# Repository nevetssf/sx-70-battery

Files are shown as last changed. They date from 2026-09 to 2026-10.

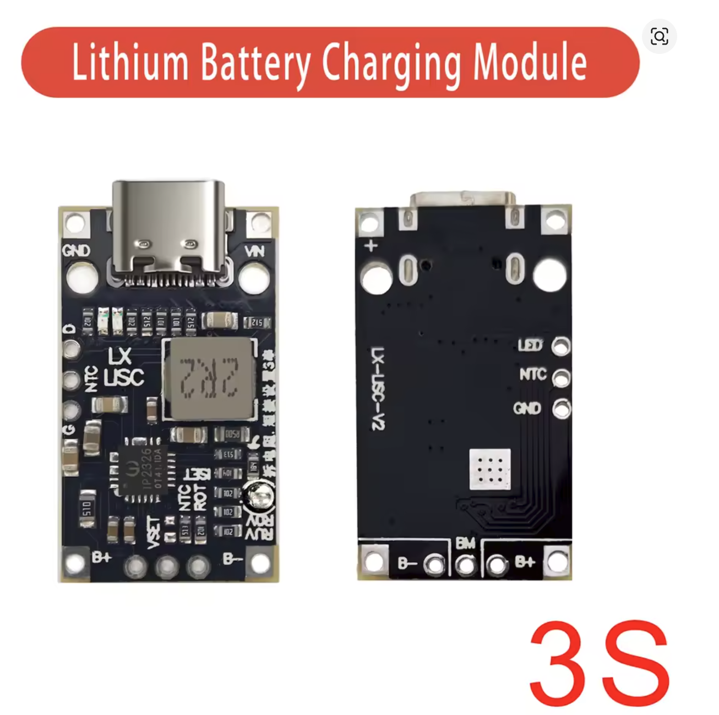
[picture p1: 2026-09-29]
hardware/bom/U2-ip2326-charger/ip2326-black-3s-lx-lsc-v2-front-back.png

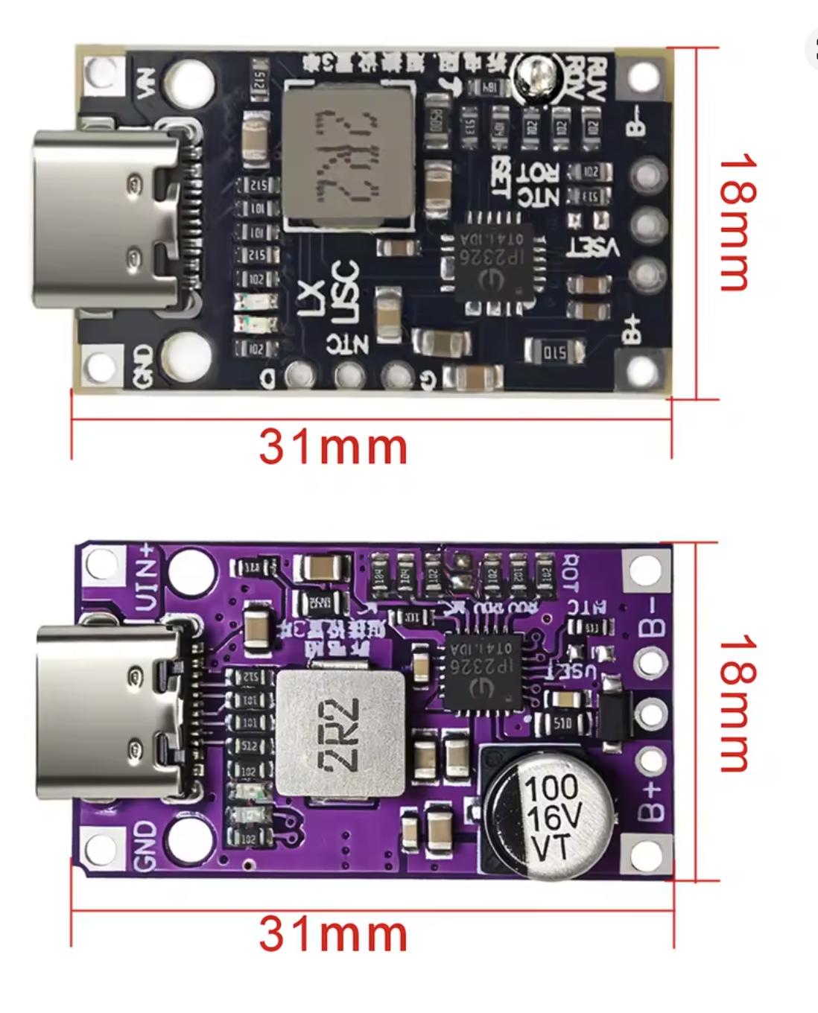
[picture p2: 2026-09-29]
hardware/bom/U2-ip2326-charger/ip2326-dimensions-31x18mm.png

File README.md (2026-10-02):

# SX-70 External Power Pack

A rechargeable, camera-mounted power supply for the folding Polaroid SX-70, replacing the PolaPulse cell in the film pack. Aimed at battery-less film (i-Type), dead packs, and bench work.

**Status: design v0.4, not yet built.** Nothing has been measured on a camera yet. See [Where things stand](#where-things-stand).

## Where things stand

**Settled**

| | |
|---|---|
| Camera interface | Two **pogo pins** onto the base-plate contacts, through 3 mm holes in the skin. **No soldering to the camera** |
| Mounting | Magnets bonded into the pack base, against a VHB-bonded steel shim on the camera |
| Enclosure | 3D printed PETG, M2.5 brass heat-set inserts, magnet pockets and pogo bosses in the base |
| Architecture | Still two options. The measured motor peak current decides between them |
| Envelope (Option B) | **86 × 50 × 17.7 mm** |

**Ordered** — replacement flex parts, in case a flex fails (see [flex-order.md](docs/flex-order.md))

- **Body flex** — Cundari's replacement, ordered from PCBWay, shipped Sept 2026
- **Motor control chips** — 10 assembled boards from PCBWay, ~$135 the lot, Sept 2026, 18–20 day quoted build

Order numbers, the cost breakdown and vendor correspondence are kept out of the repo in a gitignored `private/` folder.

**Not yet ordered** — [digikey-order.csv](hardware/bom/digikey-order.csv) is the consolidated list. Pogo pins, the 0.1 Ω shunt and the R1 spread are the ones that unblock bench work. The LiPo, IP2326, TPS630702 regulator (LCSC), magnets and inserts come from other suppliers.

**Blocked on bench measurement** — all three in [testing.md](docs/testing.md), and everything downstream waits on them.

## The problem

The SX-70 draws all its power from the film pack's battery. i-Type and Go film packs have no battery, and old SX-70 packs are frequently dead, so the camera appears completely inert. A PolaPulse supplies about 6 V with roughly 0.5 Ω of internal resistance, and that impedance is an accidental but useful current limiter during a jam. Any replacement needs to supply ~6 V *and* not be a stiff, low-impedance source.

## Two architectures

Both feed the camera through **two pogo pins onto the base-plate contacts** — no soldering to the camera. See [Camera connection](docs/design.md#camera-connection).

### Option A — 4× regulated 1.5 V AAA (no converter)

Four XTAR 1.5 V Li-ion AAA cells in series give a flat 6.0 V with no buck converter, no charge circuit, and nothing to tune. Simplest possible build; matches the Retrospekt approach.

- **Gating spec:** each cell is rated 2 A max, so the string is capped at 2 A.
- Charging happens off-camera in an XTAR charger.
- Energy: ~6.5 Wh.

### Option B — 2S LiPo + USB-C charger + buck-boost regulator

A small 2S LiPo, an IP2326 USB-C boost charger with cell balancing, and a TPS630702 buck-boost regulator on the carrier PCB, set to 6 V by a feedback divider. It holds 6 V across the whole pack range; the Pololu D30V33MALCMA fine-adjust module is the fallback ([why](docs/design.md#regulator--tps630702-replaced-the-pololu)).

- Charges in place over USB-C; output set by the feedback divider to whatever the camera actually needs.
- Ample peak current (30C on a 350 mAh pack is >10 A).
- Energy: ~2.6 Wh, still several hundred exposures per charge.
- Balancing is passive and only runs at the end of the charge, so let the taper finish instead of unplugging at "nearly full" — the protection board will not correct drift on its own ([details](docs/design.md#balancing)).

```
Option A:  4x AAA (6.0 V) --> SW --> C1 --> R1 --> pogo pins --> camera base-plate

Option B:  USB-C --> IP2326 --> 2S protection --> 2S LiPo
                       |                            |
                     (BM balance)                   v
                            SW (EN) --> TPS630702 --> C1 --> D1 --> R1 --> F1 --> pogo pins --> camera
```

C1 and R1 (0.22–0.47 Ω) appear in both. C1 is 1000 µF low-ESR in Option A and 2 × 220 µF polymer in Option B, where the TPS630702 caps output capacitance at 470 µF. The capacitor is for motor inrush, the resistor to emulate PolaPulse source impedance. D1 (SS34 Schottky) blocks backfeed when a battery-equipped film pack is loaded; Option B adds F1, a resettable PTC fuse that ends a sustained force-charge fault ([details](docs/design.md#2-ptc-backstop--one-part)). **The pogo pins' own contact resistance (40 mΩ for the pair) counts against R1's budget** — measure and subtract.

## Repository layout

```
docs/design.md        Full design notes, calculations, rationale
docs/testing.md       Bench procedure and the measurements that settle open questions
docs/flex-order.md    Replacement body/lens flex: routes and PCBWay order prep
docs/pcb.md           Carrier PCB: constraints, outline, placement, nets, fab spec
hardware/enclosure/   Parametric OpenSCAD enclosure
hardware/bom/         Bills of materials, plus per-part reference material in <ref>-<part>/
hardware/flex-lens/   Lens/shutter flex reverse-engineering: scan spec, KiCad setup, fab drawing
scripts/build_stl.py  Render every STL variant
```

## Building the enclosure

The shell is parametric for both options:

```bash
python scripts/build_stl.py          # renders lipo_{base,lid}.stl and aaa4_{base,lid}.stl
```

Or open `hardware/enclosure/sx70_power_pack.scad` in OpenSCAD and use the Customizer. Set `battery_option` to `lipo` or `aaa4`.

Print in **PETG** (sustained load, possible heat), base floor-down. All component envelopes are placeholders — caliper the real parts and update the parameters before printing a final shell.

The lid closes on **four M2.5 brass heat-set inserts** with countersunk machine screws, and the pack is held to the camera by **four 6 × 2 mm magnets epoxied into pockets in the base**, mating to a steel shim on the camera. Install inserts before bonding magnets — both involve heat. Two **spring-loaded pogo pins** pass through the camera-facing face into the base-plate contacts. Both the magnet pockets and the pogo bores need internal bosses, and those bosses set the shell height; see [Mechanical](docs/design.md#mechanical).

## Open questions

- [ ] **Are the base-plate contacts a real power rail?** The whole pogo-pin approach rests on this and it is unverified — the community calls them "test points". Watch the voltage there while firing: a rail sags under load, a test tap collapses. [testing.md step 0](docs/testing.md)
- [ ] **Camera floor voltage.** Walk a bench supply down in 0.1 V steps and find where cycling degrades. Sets the regulation target.
- [ ] **Motor peak current.** Measure inrush, sustained and stalled-rotor current with a 0.1 Ω shunt. If the peak is below ~1.8 A, Option A wins on simplicity. Above 2 A, Option B.
- [ ] **Contact spacing and pin diameter.** `pogo_spacing` and `pogo_body_d` in the SCAD are placeholders. Measure your own base plate and the pins you buy.
- [ ] **Does Option A need D1 too?** Option B has the Schottky; Option A's BOM does not. Both now connect to the same rail as the film-pack battery, so the backfeed case looks identical. Decide deliberately rather than by omission.
- [ ] **Option A shell is too small.** The 46 mm AAA holder fouls the corner lid bosses in a 48 mm cavity. Needs widening if Option A survives the current measurement.
- [ ] **Force-charging a film-pack battery.** D1 blocks film → pack but not pack → film. Decide between the procedural mitigation and a sense-and-latch inhibit.
- [ ] **Mounting location.** Magnets-in-pack against a VHB-bonded steel shim is settled; *where* on the camera base is not. Must clear the film door and keep magnets away from the motor and shutter solenoid. Re-shoot a test frame after mounting.
- [ ] **Magnets vs pogo spring force.** Two pins push back 100–300 g. Test holding force with pins fitted and compressed.

## Safety notes

- **Switch the pack off before loading film that has its own battery** (SX-70/600). With the pack on, a depleted film battery is force-charged at up to 2 A — and a PolaPulse is a non-rechargeable zinc-chloride cell that can vent. Switched off, the pack is genuinely isolated. See [Film with its own battery](docs/design.md#film-with-its-own-battery--partial-protection-and-a-real-gap).
- Do not solder directly to lithium cells.
- Option B uses raw LiPo cells: the protection board is not optional.
- Verify contact polarity against a real film pack's battery with a meter before connecting anything.
- The pogo pins are exposed on the outside of the pack. Switch it off in a bag, and keep the reverse-polarity protection.

## License

MIT (see `LICENSE`). Consider CERN-OHL-S or -P instead if the hardware matters more than the scripts.

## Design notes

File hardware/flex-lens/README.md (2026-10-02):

# Lens / Shutter Flex — Reverse-Engineering Workspace

Replacement for the SX-70 lens (lensboard/shutter) flex. There is **no open-source design for this one** — Cundari's board is the *body* flex, and PolaStudio's lens flex was sold out as of Sept 2026. So this is a scan-and-retrace job. Routes and order prep: [../../docs/flex-order.md](../../docs/flex-order.md).

```
scan/    Source scans of the original, plus the scale calibration record
kicad/   KiCad project (create it here — see below)
fab/     Fabrication drawing notes and the PCBWay submission package
```

## Before anything else

1. **Continuity-map the original**, then **scan it**, then store it flat. The substrate keeps degrading and the geometry is unrecoverable once it crumbles. See [scan/README.md](scan/README.md).
2. **Identify which regions actually move when the camera folds.** This is the single most important input to the design, because it decides copper type, bend radii and whether copper can exist on both layers in those zones. Fold and unfold the camera with the original in place and mark the moving areas on a printout of the scan.
3. Cross-check the 7-way flex pinout in [OpenSX70 — For Dummies part 2](https://opensx70.com/tutorials/opensx70-for-dummies-2/) against your own continuity map. The author flags some details as uncertain; trust your meter over the page.

## KiCad project

The `.kicad_pcb` / `.kicad_pro` files are deliberately not generated. Unlike the carrier PCB (built by `scripts/build_kicad_pcb.py`), this board is traced by hand from a scan, so there is nothing to script. Create the project with **File → New Project** into `kicad/`, then apply the settings below. `kicad/sx70_lens_flex.kicad_dru` is provided and will load into Board Setup → Custom Rules.

### Board Setup

| Setting | Value |
|---|---|
| Layers | Start **single-sided** if the original is. Only go 2-layer if the scan proves it |
| Board thickness | 0.12 mm (matches the reference body flex; adjust to your measurement) |
| Solder mask | Treat `F.Mask` / `B.Mask` as the **polyimide coverlay** openings. KiCad has no coverlay concept — say so on the fab drawing |
| Edge.Cuts | The profiled outline. Laser or die cut, so it must be exact and closed |
| User.1 | Stiffener outlines |
| User.2 | Bend areas and bend-axis lines |
| User.Drawings | Dimensions and fab notes |

### Design rules

Starting values, loaded from the `.kicad_dru`. **Confirm against PCBWay's live flex quote form before fabbing** — I have not verified their current flex minimums, and they differ from the rigid-PCB figures.

- Min track width: 0.15 mm general, 0.20 mm for anything carrying motor or solenoid current
- Min clearance: 0.15 mm
- Min track width in bend zones: 0.20 mm, and keep it constant across the bend

### Tracing the scan

KiCad 7+ places a bitmap directly on the board as a reference image — set its scale from the ruler in the scan, then draw copper over it. For the outline, trace to vector first and bring it in as DXF at 1:1 in millimetres, onto `Edge.Cuts`.

Do what Cundari did on the body flex: don't reproduce the original slavishly. Add anything useful while you're in there.

## Flex design rules that differ from rigid PCB

These are what make a flex survive. Most are invisible to DRC — they are on you.

**In bend areas:**

- **Copper on one layer only.** Copper stacked on both layers through a bend creates an I-beam that cracks. If the region bends, keep it single-layer.
- **No plated through-holes, no vias.** Ever.
- Traces cross the bend **perpendicular to the bend axis** — straight across the fold. Never run a trace parallel to the bend line inside the bend zone.
- **Constant trace width** through the bend. No pads, no width steps, no tear-drops mid-bend.
- **Hatched, not solid, copper pours.** Solid copper stiffens the zone and fatigues.

**Bend radius**, as a multiple of total thickness — at 0.12 mm:

| Use | Multiple | Minimum radius |
|---|---|---|
| Formed once on assembly | 6× | 0.72 mm |
| Folded occasionally (the camera folding) | 10–20× | 1.2–2.4 mm |
| Continuous flexing | 100× | 12 mm |

The camera's fold is the middle row. Specify **rolled-annealed (RA) copper** rather than electro-deposited — ED copper is fine for a static flex and cracks in one that folds. Ask for it explicitly; it is not always the default.

**Everywhere else:**

- Radius the outline corners. Sharp internal corners are tear-initiation points.
- Curved or 45° trace corners, never 90°.
- **Teardrops at every pad-to-trace junction** — the classic flex failure is the trace cracking right where it meets the pad.
- **Anchor pads** (small spurs under the coverlay) for isolated pads, which otherwise peel.
- Stiffeners under every connector and hand-solder pad area. Call out material, thickness and exact location on the drawing.

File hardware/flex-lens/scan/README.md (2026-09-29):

# Scanning the Original

Do this **before** any further handling. The flex degrades with every touch, and a good scan is the only insurance against the original crumbling mid-project.

## Method

- **Flatbed scanner only.** A phone or camera introduces lens distortion and perspective error that will quietly scale your outline wrong.
- **2400 dpi optical** (not interpolated). 1200 is a usable floor if 2400 is not available.
- **Put a steel rule in the frame**, in the same plane as the flex, on every scan. This is the scale reference and it is not optional — scanner dpi is nominal and drifts between axes.
- Scan **both sides**. Include the outline and at least two through-features (holes, notches) visible from both, to register the two images.
- Save **lossless** — TIFF or PNG. Never JPEG; the compression artefacts blur trace edges exactly where you need them sharp.
- Support a curled flex flat with light pressure from the lid only. **Do not force a crumbling substrate flat** — scan it as it lies and correct later. A cracked original is worth less than an imperfect scan.

## Record here

| Field | Value |
|---|---|
| Camera / body ID | |
| Which flex | Lens / shutter |
| Scan date | |
| Scanner + dpi | |
| Scale reference | e.g. steel rule, mm |
| Measured px/mm (X, Y) | |
| Files | |
| Condition notes | cracks, missing sections, prior repairs |

## Continuity map

Meter the original before storage and record net-by-net here, including which pads connect to the 7-way body interface. Cross-check against [OpenSX70 For Dummies part 2](https://opensx70.com/tutorials/opensx70-for-dummies-2/), but trust the meter.

## Storage

Flat, between parchment, in a rigid card sandwich, in a labelled bag. Minimise handling.

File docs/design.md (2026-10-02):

# SX-70 External Power Pack — Design v0.4

Rechargeable external supply for the folding SX-70, replacing the PolaPulse battery when shooting battery-less film (i-Type) or dead packs.

Two architectures are carried in parallel until the bench measurements in [testing.md](testing.md) settle the choice. **Option A** (4× regulated 1.5 V AAA, no converter) is simpler and wins if the motor's peak draw stays under ~1.8 A. **Option B** (2S LiPo + USB-C charger + buck-boost regulator) is the fallback and is detailed first below.

Camera batteries were ruled out early: no bare NP-FW50 socket is sold anywhere — only dummy batteries, which are the wrong gender — and the NP-F holders that do exist are ~89 × 96 mm.

**Envelope:** Option B **86 × 50 × 17.7 mm** — 9 mm inside the 95 mm camera-bottom limit, after the TPS63070 replaced the Pololu module. Option A ~77 × 52 × 18.7 mm. Height is now set by the PCB stack (floor + 2.6 mm standoff + board + tallest part), not by internal bosses. Layout drawings: [layout-top-lipo.svg](../hardware/enclosure/layout-top-lipo.svg), [layout-top-aaa4.svg](../hardware/enclosure/layout-top-aaa4.svg).

---

## Camera constraints — measured

| | | |
|---|---|---|
| Max width of the camera bottom | **95 mm** | Hard ceiling on the pack's long axis |
| Base-plate contact spacing | **~50 mm** | **Provisional** — to be confirmed on the next camera opened |

The other pack axis runs along the camera's ~170 mm length and can grow freely. The 50 mm spacing exceeded the old 46 mm electronics bay, which is what drove the pack to an L-shaped carrier board — see [pcb.md](pcb.md).

---

## Design goals

- Supply ~6 V to the camera's **base-plate contacts**, with source impedance similar to a PolaPulse (~0.5 Ω), so a jam can't dump unlimited current through the motor. (See *Power* in the servicing notes.)
- Charge in place over USB-C, with cell balancing.
- Near-zero drain when switched off.
- No backfeed conflict when a battery-equipped SX-70/600 pack is loaded.
- **Camera stays electrically unmodified.** Pogo pins press onto existing contacts; the only irreversible step is a 3 mm hole in the skin. Nothing is soldered to the camera.

---

## Block diagram

```mermaid
flowchart LR
  USB[USB-C 5V] --> CHG[IP2326 2S boost charger]
  CHG -- "B+ / B−" --> BMS
  CHG -. "BM (midpoint)" .-> CELLS
  CELLS[2S LiPo 350 mAh] --> BMS[2S protection board]
  BMS -- "P+ / P−" --> REG[TPS630702 buck-boost, 6 V]
  SW[Slide switch] -- "EN via R6/R7 divider" --> REG
  USB -. "VBUS → Q1 pulls EN low" .-> REG
  REG --> C[2 × 220 µF polymer]
  C --> D[SS34 Schottky]
  D --> R[0.22 Ω 1 W]
  R --> F[1812L075 PPTC]
  F --> P[2x pogo pins]
  P --> CAM[SX-70 base-plate contacts]
```

---

## Option B — bill of materials

| Ref | Part | Notes |
|---|---|---|
| B1 | [Gens Ace 350 mAh 2S 30C LiPo (GEA3502S30JST)](https://store.hobbyetc.com/parts/view/186378) | 35 × 26 × 10 mm, 17 g. Use the balance lead for the midpoint. |
| U1 | 2S protection board (DW01/8205-class or similar) | Overdischarge ~2.8–3.0 V/cell, overcurrent ≥ 5 A. Rides on top of the pouch with Kapton between. |
| U2 | IP2326 2S USB-C boost charger module ([example listing](https://sigmanortec.ro/en/lithium-2s-3s-charging-module-with-balancing-type-c-voltage-booster), [IP2326 datasheet](https://wmsc.lcsc.com/wmsc/upload/file/pdf/v2/lcsc/2304062030_INJOINIC-IP2326_C2832094.pdf)) | ~31 × 15 mm. **Reduce charge current**, see below. |
| U3 | [TPS630702 buck-boost, 2–16 V in, 2.5–9 V / 2 A out](https://www.lcsc.com/product-detail/C109322.html) | QFN on the carrier PCB, with L1 1.5 µH, Cin 2 × 10 µF, Cout 3 × 22 µF. Output set to 5.99 V by R2/R3 = 649 k / 100 k. See [Regulator](#regulator--tps630702-replaced-the-pololu) |
| U3-alt | [Pololu D30V33MALCMA, 1.4–7 V 3.8 A fine-adjust w/ low-voltage cutoff](https://www.pololu.com/product/4852) | Fallback only. ~$35, step-down, 0.9″ × 1.2″. Check stock — the family was backorder-only. |
| C1a, C1b | 220 µF 10 V low-ESR polymer (440 µF total) | On regulator output, *before* D1/R1. The TPS630702 allows 470 µF max on VOUT, so 1000 µF is out. |
| F1 | Littelfuse 1812L075 PPTC | After R1. Ends a sustained force-charge fault — see [Choosing the PTC](#choosing-the-ptc--the-obvious-part-is-the-wrong-one) |
| D1 | SS34 (3 A 40 V Schottky) | Blocks backfeed from a film-pack battery. |
| R1 | 0.22 Ω 1 W | PolaPulse impedance emulation; tune after shunt measurements. |
| SW1 | SS12D00 SPDT slide switch | Pulls EN low for off. |
| P1 | [Mill-Max 7982-1-15-20-75-14-11-0](https://www.digikey.com/en/product-highlight/m/millmax/high-current-small-scale-spring-loaded-pins) spring-loaded pin, through-hole (×2) | 8 A (6.4 A derated), 20 mΩ max, 0.7 mm stroke, 60 g mid-stroke, 2.1 mm body, gold throughout. ~$1.55 ea at Digi-Key. Soldertail into the carrier PCB |
| PCB1 | Carrier PCB, 2-layer | Carries P1, C1a/C1b, D1, R1, F1, SW1, J2, J3, J4, the regulator and the IP2326 module. See [Carrier PCB](#carrier-pcb) |
| — | M2.5 brass heat-set inserts, 3.5 mm OD × 4 mm (×4) | Lid fixing. Measure yours — OD and length vary by supplier; `insert_d`/`insert_l` in the SCAD. |
| — | M2.5 × 8 mm countersunk machine screws (×4) | Lid. Length covers lid + lip + insert. |
| — | Neodymium discs, 6 × 2 mm (×4) | Bonded into the base. N52 if the holding test is marginal. |
| — | Steel shim, 0.3–0.5 mm + 3M VHB | Camera side. Ferrous — not stainless, much of which is not. |
| — | Slow-cure epoxy | Bonding magnets. Not CA: it is brittle in shear and lets go when the pack is twisted off. |

---

## Electrical notes

### Charge current — and the 1C target may not be reachable

The module ships at ~1.4–1.5 A, about **4C** on a 350 mAh pack. That must come down. Current is set by the **ISET** resistor:

| ISET | Charge current |
|---|---|
| 60 kΩ | 1.5 A |
| 75 kΩ | 1.2 A |
| 100 kΩ | 0.9–1.0 A |
| 120 kΩ | 0.75 A |
| **180 kΩ** | **0.5 A** |

**0.5 A appears to be the floor.** The documented range is 120–60 kΩ, with 180 kΩ/0.5 A the lowest figure found anywhere. Our 350 mA target would need ~257 kΩ, outside anything documented — so **1C on a 350 mAh pack is probably not achievable with this chip.**

Two ways out:

1. **Accept 0.5 A ≈ 1.4C.** A 30C-discharge pouch will survive it; cycle life suffers somewhat. Simplest.
2. **Go to a ~500 mAh pack**, which makes 0.5 A exactly 1C. Capacity was never the constraint, so the only cost is footprint — and the battery zone is currently sized 35 × 26 mm for the 350 mAh cell, so **check a 500 mAh pouch still fits before committing.**

Either way: fit the resistor, then **verify with an inline USB-C meter** before trusting it.

### The specific module — Z-6732-V4.0 (purple, 2S)

Confirmed from the vendor photo:

| | |
|---|---|
| Chip | **IP2326** — marking verified, not a house code |
| Config | 2S variant |
| Front pads | `GND`, `VIN+` (so it can be fed without USB-C), `B+`, `B−` |
| Back pads | `LED`, `NTC`, `GND`, and **`BM`** between `B−` and `B+` |
| Silkscreened config points | `ISET`, `NTC`, `ROV` |
| Mechanical | 4 plated corner mounting holes; 2.2 µH inductor; 100 µF 16 V electrolytic |

Three things follow:

- **`BM` is broken out**, so balancing is actually available. This was the one feature the whole drift analysis depends on, and plenty of 2S modules omit it.
- **It is a charger, not a BMS**, whatever the listing says. There are only `B+`/`B−` pads — no `P+`/`P−`, no second protection IC, no pair of MOSFETs. **U1 is still required**, and the charger's B+/B− still route through U1's P+/P−.
- **`ROV` is the 3S select, not a spare pad.** Bridging it and removing the adjacent resistor converts the board to 3S, which is exactly the mode with no balancing. Leave it alone.
- **Order by the 2S/3S dropdown, not by colour.** The vendor sells 2S and 3S in both purple and black, and their photos pair black with the 3S board (`LX-LSC-V2`). **The 3S board carries a `BM` pad too**, in the same place — but the chip does no balancing in 3S, so that pad is decoration. Confirm the order says 2S.

`NTC` being broken out means the pouch thermistor is available if wanted — leave it unused otherwise.

**Identify the ISET resistor by the silkscreen, then measure it**, rather than trusting a value read off a photo. Three-digit codes decode as XY × 10^Z, so `184` is 180 kΩ and `104` is 100 kΩ. Several resistors on this board share those codes and only one is ISET.

**Height note:** the 100 µF electrolytic is the tallest thing on the module, and it stacks on top of the carrier PCB's own standoff. The height budget only has 0.3 mm of slack, so **measure the module's overall height before finalising the enclosure.**

### Balancing

**Balancing exists only in 2S mode.** The chip has no 3S balancing at all, and listings claiming otherwise are a reliable sign the vendor does not understand the part. 2S is our configuration, so this works in our favour — but it means the module must be left in its default 2S state: **CON_SEL floating**, the 2S/3S pad *not* bridged.

Balance current is 20–40 mA, set by Rcb (Icb = Vcb / Rcb, Rcb > 100 Ω) — which is the "tens of mA" figure the drift analysis below assumes.

Wire the IP2326 **BM** pad to the cell midpoint (centre wire of the balance lead). B+/B− go to the protection board's **P+/P−**, not directly to the cells, so the BMS guards charging too.

**The protection board does not balance.** A DW01/8205-class board only cuts off on per-cell over/under-voltage. If the cells drift apart it will trip on the high cell and end the charge early, leaving the pack progressively less full — it never corrects the imbalance. Balancing is the IP2326's job alone, which is why BM has to be connected.

**What BM balancing actually does.** It is passive top-of-charge balancing: during the CV taper the IP2326 bleeds the higher cell through an internal shunt at tens of mA. Two consequences:

- It corrects *slow drift* between reasonably matched cells. It will not rescue a badly mismatched pair — with tens of mA against a 350 mAh pack, closing a large gap takes many hours spread over many charges.
- **It only happens at the end of the charge.** Unplugging at "nearly full" skips the balancing phase entirely. If you habitually pull USB-C early, the cells will drift and nothing will ever pull them back. Leave it connected through the taper, and give it an occasional deliberate full charge.

**Starting matched.** B1 is a commercial 2S pack, so its cells arrive matched from the factory and this mostly takes care of itself. If you ever rebuild from loose cells, charge each to 4.20 V individually before assembling in series, and match them on capacity and internal resistance first — mismatched cells diverge faster than passive balancing can correct.

**Drift checks.** Meter the midpoint against B− at full charge:

| Cell delta | Action |
|---|---|
| ≤ 20 mV | Normal. This is the bring-up acceptance figure in [testing.md](testing.md). |
| 20–50 mV | Watch it. Do a full charge and re-check before the next shoot. |
| > 50 mV | Top-balance externally, then find out why. |
| Won't hold after balancing | One cell is failing. Retire the pack. |

**Keep the balance lead accessible.** The Gens Ace pack's JST-XH lead is the recovery path: a hobby charger (iMAX B6 or similar) can top-balance a drifted pack far faster than BM will, and can set a 3.8 V/cell storage charge if the camera is going away for a season. Leave the connector reachable inside the shell, or bring it out — if you bring it out, recess or cap it, because a shorted balance lead shorts a cell directly with no protection board in the path.

### Output regulation and source impedance

With a fixed 6.0 V regulator, D1 + R1 would put the camera at ~5.7 V idle and ~5.2 V at 2 A. A PolaPulse sagging through its ~0.5 Ω lands in the same place at 2 A, but it starts from ~6.0–6.3 V rather than 5.7 V, so a fixed module has less headroom than the real thing.

An adjustable regulator removes the question: set the output so the **camera** sees ~6.0 V under load (roughly 6.6 V at the regulator, covering D1 and R1). On the TPS630702 that means choosing the R2/R3 feedback divider; the 649 k / 100 k pair below gives 5.99 V and will need raising once the floor voltage is known. Set the target from the measured floor voltage in [testing.md](testing.md).

Recovering headroom, in order of cost:

1. Raise the regulator setpoint (one resistor change in the FB divider).
2. Drop R1 to 0.1 Ω — the regulator's own current limit already backstops a stall.
3. Replace D1 with a P-channel MOSFET disconnect (tens of mΩ instead of ~0.4 V).

### Shooting while charging

It will work, but **switch the pack off and let it charge.** Short answer: charge, then shoot.

There is **no power path**. The IP2326 module has only `B+`/`B−` — no separate system output — so the charger and the regulator both hang off the same node, U1's `P+`/`P−`. The load sits in parallel with the battery during charge rather than being fed separately.

Three consequences, in order of how much they matter:

- **Charge termination gets confused.** The IP2326 terminates on current taper. Load current at the same node looks like charge current, so the charger may taper late or never reach termination. Not dangerous — CV still clamps at 8.4 V and U1 still guards — but the pack's "full" indication stops meaning anything.
- **Balancing may never run.** Passive balancing only happens during the CV taper (see [Balancing](#balancing)). If load current prevents a clean taper, the one mechanism correcting cell drift never engages. This is the real reason to avoid it: the harm is slow and invisible.
- **The charger cannot supply a shot.** At 0.5 A into 8.4 V it delivers ~4 W; an exposure pulls ~12 W. The pack supplies the surge regardless, so charging buys nothing during the shot itself.

SW1 disables the regulator, not the charger, so charging with the pack switched off is the normal case and needs no extra hardware.

At 0.5 A a 350–500 mAh pack is full in roughly an hour, and a charge lasts hundreds of exposures — so there is no real scenario where shooting tethered is needed. A USB-C cable hanging off a folded SX-70 is its own argument.

**If tethered operation ever became a requirement**, the fix is a proper power-path front end, not a workaround — an ideal-diode load-share between charger, pack and regulator. That is a different charger IC, not a tweak to this one.

### Interlock — disable the output whenever USB is connected

Better than relying on discipline: make the two states mutually exclusive in hardware.

**Do not try to switch the charger off.** Two reasons it does not work:

- The module exposes no enable pad — only `GND`, `VIN+`, `B+`, `B−`, `LED`, `NTC`, `BM`.
- Switching VBUS instead would put **~0.93 A** through SW1 (4.2 W of charge at 5 V input, 90% efficient). An SS12D00-class slide switch is rated about 0.3 A. It would not last.

**Switch the regulator instead.** Pull the TPS630702's `EN` low whenever VBUS is present:

```
EN is high only when:  SW1 is on  AND  no USB connected

module VIN+ ──[100k]──┬── gate, 2N7002
                      └──[100k]── GND
                         drain ── EN node
                         source ── GND
```

Three things make this cheap: the module already breaks out `VIN+`, so VBUS needs no extra wiring; `EN` draws 0.2 µA max, so nothing has to drive current; and the part count is one small MOSFET and two resistors, well under $0.10.

It is also failure-safe in the right direction — unplug USB and the camera works again, with no state to get stuck in.

### Bonus: the same pin gives back the soft LVC

The TPS6307x has a **precise** EN threshold (0.77–0.83 V rising, 0.67–0.73 V falling) specifically so it can serve as a user-defined undervoltage lockout. That is the adjustable low-voltage cutoff we gave up when dropping the $35 Pololu — available here for two resistors.

A divider from the pack to `EN`, sized to cross the threshold at the chosen cutoff:

```
R_top = 698 kΩ, R_bot = 100 kΩ
Vpack 6.4 V → EN 0.802 V   (at the rising threshold)
divider draw at 7.4 V ≈ 9.3 µA
```

This cuts off gently at ~6.4 V, above U1's 2.8–3.0 V/cell hard cutoff, so the BMS stays a backstop rather than the normal stopping point — better for cell life.

**Put SW1 in series with the divider's top leg**, not across `EN`, so switching off removes the 9.3 µA as well. Otherwise it runs continuously and eats into the 2 µA shutdown figure that makes the standby budget work.

The MOSFET interlock and the LVC divider both act on `EN` and compose without conflict: the divider sets the floor, the MOSFET overrides to off.

### Switch-off drain

With the regulator disabled the standby draw is well under 100 µA including the protection board — months of shelf life. Top up every couple of months and before a shoot.

### Capacity

350 mAh at 7.4 V is ~2.6 Wh, ~2.2 Wh usable. A cycle costs roughly 1.5–2 A at ~6 V for about a second, ~0.003–0.005 Wh with electronics included: **400–600 exposures per charge**, or 50–70 film packs. Capacity is not the constraint; peak current is.

### No bleed resistor

The bench dummy pack uses ~1 kΩ bleed. It's omitted here deliberately: with a battery-equipped film pack loaded, a bleed after D1 would drain the film's battery at ~6 mA continuously.

### Film with its own battery — partial protection, and a real gap

**What is protected**

- **D1 blocks film → pack.** A Schottky in the output path stops a film battery backfeeding C1 and the regulator.
- **Switched off, the pack is fully isolated.** The TPS630702 disconnects the load in shutdown, so with SW1 off there is no path at all, in either direction. The output discharge also drains C1, and D1 stops that touching the film battery.

**What is not protected**

**D1 is a one-way device, and nothing stops the pack driving current *into* a film-pack battery.** That direction is forward-biased through D1. With the pack switched on and a battery-bearing film pack loaded:

| Film battery | Result |
|---|---|
| Fresh, 6.2 V | Higher than our ~5.6 V at the pins — **D1 blocks, nothing flows** |
| Part-used, 5.0 V | **~0.67 A** pushed into the cell |
| Dead, 3.0 V | **2 A**, the regulator's limit, sustained |

The loop is R1 (~0.35 Ω) + pogo pins (0.04 Ω) + the PolaPulse's own ~0.5 Ω, so roughly 1 Ω — nothing meaningful limits it.

**A PolaPulse is a zinc-chloride primary cell. It is not rechargeable and can vent or leak.** Inside the film compartment.

**The bad case is the main use case.** This pack exists partly to revive cameras whose film-pack battery is flat — and a flat film battery is exactly the condition that produces the highest fault current. A fresh pack is safe; a dead one is not. That is the wrong way round.

**Current mitigations, all procedural**

1. **Use i-Type film**, which has no battery. The design intent, and it makes the whole question moot.
2. **Switch the pack off** before loading battery-bearing SX-70/600 film. Genuinely safe, because of the load disconnect — not merely "best practice".
3. Never leave the pack switched on with a battery-bearing pack loaded.

**Hardware options, in order of cost**

### 1. Procedural only — status quo

Zero parts. Relies on switching off before loading battery-bearing film. Safe when followed, because the load disconnect is real.

### 2. PTC backstop — one part

A resettable fuse in the output path. It does not *prevent* the fault, it ends it.

- The motor pulse is ~2 A for ~1.5 s then idle, so the device cools between shots. The fault is ~2 A **sustained**. A PTC with roughly 1 A hold / 2 A trip takes seconds at 2 A — it trips on the fault and survives a single cycle.
- **Its hold resistance (0.1–0.3 Ω) sits in the same loop as R1**, so it substitutes for part of R1 rather than adding to it.
- **Risk: nuisance tripping.** Eight shots back to back is the case to test, and PTC resistance drifts with temperature, so source impedance stops being a fixed number.

Cheap and honest, but it protects the cell rather than preventing the current.

### 3. Sense-and-latch — prevents it

Sample the output node at switch-on, while the regulator is still disabled. With the output disconnected, a film-pack battery shows up there; an i-Type pack shows 0 V because the camera is dormant. **The threshold can be low — around 1 V — because it only has to answer "is anything driving this node?"** It does not need to distinguish a fresh cell from a flat one.

A latch is unavoidable. Once our own output comes up, the sense sees our voltage and would inhibit itself, so the decision has to be taken once and held.

**Discrete version** — about 11 parts, ~$1:

| | |
|---|---|
| LM393 dual comparator | 36 V rated, so it runs straight off the pack with no logic rail |
| ½ LM393 | Divided sense node against the reference |
| ½ LM393 | Positive feedback, wired as the latch |
| TLV431 | Shunt reference — a plain divider would drift with pack voltage |
| RC | Holds EN low during the sample window |
| MOSFET | Pulls EN low; can share the node with Q1 |
| LED + R | Indicator |

**MCU version** — about 9 parts, ~$0.80 plus firmware: an ATtiny202 and a small LDO. Reads the node at power-up, drives EN, shares an LED for status. More flexible — it could also show charge state or blink codes — at the cost of putting firmware in an otherwise analog design.

Either needs roughly **15 × 10 mm**, against about 20 × 8 mm currently free in the main body. Tight, and it may grow the board.

**Two things to weigh before building it**

- **Adding protection adds a failure mode.** A false inhibit means the camera silently does not fire, which in the field is worse than the problem being solved. An indicator LED is not optional here.
- **Make it fail toward inhibit**, so a dead sense circuit refuses to run rather than quietly removing the protection.

**Decision: option 2, the PTC.** The pack is built for i-Type film where this fault cannot occur, and switching off is genuinely safe rather than merely advised. Option 3 would earn its complexity only if the pack were used by someone else, or if battery-bearing film became routine.

### Choosing the PTC — the obvious part is the wrong one

**F1 = Littelfuse `1812L075`**, 1812 SMD, in the output path beside R1.

| Part | I_hold | I_trip | Against a 2.0 A fault |
|---|---|---|---|
| 1812L110 | 1.1 A | 2.2 A | **Below I_trip — may never trip.** Useless here |
| **1812L075** | **0.75 A** | **1.5 A** | 1.33 × I_trip — trips |

The 1.1 A part is the common one and the first thing you would reach for, but our fault is regulator-limited to 2.0 A, which sits in its indeterminate band between hold and trip. It could sit there indefinitely doing nothing.

**The window is narrow and cannot be closed on paper.** The fault and the motor pulse are the *same* 2.0 A, separated only by duration. The 1812L075 must trip on a sustained 2.0 A while surviving a ~1.5 s pulse at the same current — that is 1.33 × I_trip, where trip time is a few seconds. Close enough that it needs measuring.

**Buy both values and decide after [testing.md](testing.md) step 2.** If the real motor peak is higher than 2 A, both parts shift and this choice is reopened.

Two further notes:

- **Voltage rating.** The plain `1812L110PR` is rated 8 V, against 6 V across the device. Adequate but slim; the `/16` variants give more headroom for no real cost. Check the rating on whichever value is chosen.
- **It substitutes into R1's budget.** Hold resistance is 40–210 mΩ, in the same loop as R1 and the pogo pins. **Measure the fitted device and reduce R1 to match**, exactly as for the pins — otherwise the source impedance lands high.

---

## Camera connection

**Pogo pins onto the camera's base-plate contacts. No soldering to the camera at all.**

> **Assumption to confirm:** "the terminals on the camera" is read here as the **two power test contacts on the underside of the base plate**, behind the existing holes in the plastic base and hidden by the skin. That matches a bottom-mounted magnetic pack. If the intent is the *film-chamber* battery contacts instead, pogo pins cannot reach them from outside the film door and this section needs rethinking.

- Two **spring-loaded (pogo) pins** on the pack's camera-facing face, pressing into the base-plate contacts through the skin.
- **Skin modification:** mark through the existing base-plate holes, puncture, and round the opening to roughly **3 mm diameter**. The base plate itself is not modified. This is the only irreversible step.
- Establish polarity from a real film pack's battery with a meter before connecting anything.

### Why this is the better route

The previous plan soldered a pigtail to the traces feeding the film-chamber contacts. That meant putting a 350 °C iron on 50-year-old flex whose adhesive releases almost immediately under heat — bench 1-B lifted pads and traces on the first switch at 415 °C. **Pogo pins remove that risk entirely**, and with it the main reason this project might have destroyed a working body flex. Replacement routes remain documented in [flex-order.md](flex-order.md), but they are now insurance rather than an expected cost.

### What pogo pins add to the design

Specified part: **Mill-Max 7983-1-15-20-75-14-11-0**, from their high-current small-scale family. Real numbers, which settle three things I had estimated:

| | Spec | Note |
|---|---|---|
| Current | **8 A**, 6.4 A derated at 30 °C rise | Against a ~2 A peak. Enormous margin, and it removes current as a concern entirely |
| Contact resistance | **20 mΩ max** each | Pair in series = **40 mΩ**, not the ~0.1 Ω I first assumed |
| Spring force | **60 g** at mid-stroke | Pair = **120 g**, at the low end of my 100–300 g estimate — good news for the magnets |
| Stroke | **0.7 mm** | **Less than the ≥1 mm I specified.** See below |
| Body | 2.1 mm dia, 9.5 mm long, gold throughout | `pogo_body_d` corrected from 1.7 to 2.1 mm |
| Cycle life | 1,000,000 at half stroke | Irrelevant here, but it means nothing to worry about |

- **Current rating is no longer the gating spec.** Worth knowing why this family and not the obvious ones: Harwin's pogo pins top out at 1–2 A, and Mill-Max's standard 0906 series is spring-dependent and around 2 A. Against a 2 A peak, both are marginal. This family is not.
- **Contact resistance still counts against R1**, but at 40 mΩ it is a small correction to R1's 0.22–0.47 Ω rather than a fifth of it. Measure in circuit and subtract anyway.
- **0.7 mm stroke makes pin protrusion a measured dimension, not a tolerance sink.** This is the real design consequence. You cannot treat the pins as absorbing everything. But the seating is repeatable — magnets pull two hard, flat, bonded faces together — so the gap is fixed once built. What must be measured is the sum of skin thickness at the hole, contact recess depth behind the base plate, and magnet recess. Then set protrusion by **tuning `pogo_pad_h`**, which changes bore depth and therefore how far the plunger stands out. The SCAD echoes the resulting protrusion and warns if it falls below the stroke.
- **Gold on both plunger and sleeve**, mating a vintage nickel contact — keeps resistance low and stable.
- D1 still matters: the base-plate contacts are on the same rail as the film-pack battery, so backfeed protection is unchanged.

---

## Regulator — TPS630702 replaced the Pololu

**Decision: U3 is a TPS630702 on the carrier PCB; the Pololu D30V33MALCMA stays in the BOM as the fallback (U3-alt).** The reasoning follows.

The D30V33MALCMA is ~$35, and two of the things it is being bought for are questionable.

**Its adjustable low-voltage cutoff is largely redundant.** U1, the 2S protection board, already cuts at 2.8–3.0 V/cell. The regulator's LVC would only ever trip *earlier* and more gently. That is nice for cell life, not a safety function — and it is a meaningful part of what the $35 buys.

**It is a step-down.** As the pack falls toward 6.4 V the output sags, which the design currently tolerates because the camera runs down to ~5.2 V. A buck-boost would simply hold 6 V across the entire 2S range.

### TPS63070 on the carrier PCB

| | |
|---|---|
| Topology | **Buck-boost** — regulates through the whole 8.4 → 6.0 V pack range |
| Input | 2–16 V |
| Output | 2.5–9 V, **2 A**, 3.6 A switch current |
| Price | **~$0.90 at LCSC** (C109322, in stock) |
| Package | QFN — assembled by PCBWay alongside everything else |

Roughly **$0.90 against $35**, and technically better for this job: no sag at low state of charge.

Three consequences:

- **Footprint.** A QFN plus inductor and caps is perhaps 15 × 12 mm against the Pololu's 30.5 × 22.9 mm. The Pololu is the second-largest thing on the board and part of why the pack is 58 mm wide. It did: the layout re-run took Option B from 92 × 58 to 86 × 50 mm.
- **2 A output is exactly our assumed peak.** Fine if the real stall current is at or below that, but [testing.md](testing.md) step 2 has not been run. If the motor pulls more, this part is undersized and something like the TPS55288 is the next step up. C1 absorbs inrush, which helps.
- **Soft LVC, if wanted**, is a voltage supervisor pulling the EN pin low — a few cents, not $35.

### Setting 6 V on the TPS63070

**Order `TPS630702` (preferred) or `TPS63070`.** Both are adjustable. Avoid `TPS630701`, which is fixed at 5 V.

Output is set by a divider from VOUT to FB to GND, against an **0.8 V** reference:

```
Vout = 0.8 × (1 + R1/R2)  →  R1/R2 = 6.5 for 6.0 V
R1 = 649 kΩ, R2 = 100 kΩ  (E96 1%)  →  5.99 V
```

6.0 V sits comfortably inside the 2.5–9 V range. TI wants at least 2 µA through the divider, i.e. **R2 ≤ 400 kΩ**; 649 k/100 k draws 8 µA.

**Use the high-impedance divider, not 64.9 k/10 k.** The low-impedance version draws 80 µA continuously, which would dominate the standby budget on its own. 8 µA does not.

### Datasheet checks — resolved (SLVSC58B, Mar 2019)

**Load disconnect in shutdown: yes.** Listed in the features and stated outright: *"During shutdown, the load is disconnected from the battery."* SW1 on EN genuinely isolates the camera. **Shutdown current is 2 µA typ, 12 µA max** (−40 to 85 °C) — better than the Pololu module it replaces. The standby claim holds.

**2 A applies across our whole range.** The 2 A spec is conditioned on boost factor (VOUT/VIN) ≤ 1. With VIN 8.4 → 6.0 V and VOUT 6 V we are at or below 1 throughout, so 2 A is available until the BMS cuts.

**Start-up current limit is ~1 A** until power good asserts — that is the soft-start mechanism.

**⚠ Maximum output capacitance is 470 µF. The original 1000 µF C1 violated it.** Recommended Operating Conditions give 15 µF min / 47 µF nom / **470 µF max** on VOUT for the nominal 1.5 µH inductor. C1 must come down — 2 × 220 µF polymer (440 µF) fits. For scale, TI's own reference design uses 66 µF; 440 µF is already generous by the chip's standards. Whether it is enough for the *motor* is what [testing.md](testing.md) step 2 answers.

**Variant table — and a correction.** All three differ less than I first said:

| Part | Output | Output discharge |
|---|---|---|
| TPS63070 | **adjustable** | off |
| TPS630701 | fixed 5 V | off |
| **TPS630702** | **adjustable** | **on** |

TPS630702 is *also* adjustable — the datasheet says output discharge "is the only difference between TPS63070 and TPS630702". Only the **TPS630701** is fixed and therefore unusable here.

**Prefer the TPS630702.** Its internal discharge resistor drains the output capacitor whenever the device is disabled. With pogo pins exposed on the outside of the pack, not leaving 440 µF charged to 6 V on them is worth having. It does not conflict with the *No bleed resistor* decision below, because the discharge sits on the converter's output — ahead of D1 — so it cannot drain a film pack's battery.

### Middle option

A TPS63060-based adjustable buck-boost module, ~$6, if a module is preferred over designing the IC in. Still buck-boost, still far cheaper, but it keeps the module-footprint problem.

---

## Carrier PCB

Everything in the output path — the pogo pins, D1, C1, R1 and SW1 — sits on one 2-layer carrier board, along with the TPS630702 regulator and the IP2326 module mounted to it. Only the cells and the 2S protection board stay off-board on wires.

This started as loose modules joined by flying leads with the pins press-fitted into printed bosses. That was wrong for four reasons:

- **Pin position needs to be accurate.** With only 0.7 mm of stroke, where the plungers sit matters. A PCB holds them to ±0.1 mm; a printed boss holds them to print tolerance, which is the wrong order of magnitude for the job.
- **2 A belongs in copper, not wire.** D1, C1 and R1 are all in the motor-current path. Hand-wired, every joint adds resistance in series with an R1 we are trying to set deliberately to ±0.05 Ω.
- **C1 has to be close to the load.** Its whole purpose is supplying motor inrush. Flying leads add inductance in exactly the place that defeats it.
- **Fewer joints.** This pack gets opened repeatedly during bring-up; hand-wired assemblies fail at the joints.

### What this changes

- **P1 becomes the through-hole pin, not the solder cup.** 7982-1 instead of 7983-1 — and it is cheaper, $1.55 against $1.90. The solder cup only made sense while there was no board to solder to.
- **The printed pogo bosses are deleted.** The pins are held by the PCB. The case floor keeps only the two clearance bores for the plungers.
- **PCB standoff sets pin protrusion**, and it is a controlled dimension:

| | |
|---|---|
| Pin height above board | 5.2 mm |
| Case floor | 1.6 mm |
| Target protrusion past outer face | 1.0 mm |
| **→ PCB underside sits** | **2.6 mm above the case inner floor** |

- **The PCB clears the magnet pads.** They are 1.5 mm tall, so a 2.6 mm standoff passes over them with 1.1 mm to spare. That removes the other collision the layout drawing found — the boards no longer have to dodge the magnets.
- Height budget: floor 1.6 + standoff 2.6 + PCB 1.6 + tallest part ~10 mm = 15.8 mm, inside the 17.1 mm base with 1.3 mm spare.

### Still open

- Module mounting: headers, or castellated pads? Headers cost height, which the budget above does not have much of.
- The two modules side by side still need 37.9 mm across a 36 mm bay, so they rotate 90° or stack. See the layout drawing.
- Mounting-hole positions and outline are undefined until the layout is drawn. `pcb_posts` in the SCAD is empty until then.
- PCBWay is the obvious fab — same vendor as the flex orders, and a 2-layer board this size costs very little against the rest of the build.

---

## Mechanical

- Enclosure: `sx70_power_pack.scad`, base + lid, print in **PETG**. Boards sit on the floor on foam tape; the divider is lower than the walls so leads pass over it.
- All bay and cutout dimensions are parametric placeholders. **Caliper the actual parts** (especially USB-C height `usb_z` and switch position) before printing.
- **Option A shell:** set `battery_option = "aaa4"`. The battery bay grows to fit a 4-cell AAA holder and the electronics bay shrinks to the cap, resistor and switch.

### Lid fixing — brass heat-set inserts

Four M2.5 heat-set inserts in the base bosses, countersunk machine screws through the lid. Self-tapping screws into PETG were the earlier plan; inserts survive repeated opening, which this pack will see a lot of during bring-up.

- Boss OD is derived as `insert_d + 3.0`, leaving ~1.5 mm of PETG around the bore. Thinner than that and the insert splits the boss out sideways as it melts in.
- The bore has an `insert_lead` chamfer at the mouth so the insert starts square, and `insert_relief` of extra depth below it so displaced plastic has somewhere to go rather than jacking the insert back out.
- Insert dimensions vary by supplier. **Measure yours** and set `insert_d` (OD minus ~0.1 mm melt interference) and `insert_l`.
- Install with a temperature-controlled iron at ~200 °C for PETG, straight down. Let the boss cool before applying any screw load.

### Pogo pins

Two spring-loaded pins press through the camera-facing face into the base-plate contacts. Electrical requirements are in [Camera connection](#camera-connection); the shell side:

- Bores run through the floor into a local **2.5 mm boss**, giving ~4.1 mm of grip for the press fit. 1.6 mm of floor alone is not enough to hold a pin square under spring load.
- An outer lead-in chamfer eases the pin in and gives the skin hole something to centre against.
- Defaults place both pins in the **electronics bay**, so their solder tails are not underneath the battery. If your camera's contact spacing forces one into the battery bay, re-check the pack still fits above the boss.
- **`pogo_spacing` and `pogo_body_d` are placeholders.** Measure the contact spacing on your own base plate and the barrel diameter of the pins you actually buy.
- These bosses are now the tallest thing inside the shell, so they, not the magnets, set the external height.

### Magnet mounting

The folding SX-70 has no tripod socket, so the pack is held by **magnets bonded into the base, mating to a thin steel shim on the camera.**

- Four 6 × 2 mm discs in pockets that open on the outer, camera-facing face, sized with `magnet_fit` clearance per side for adhesive. Bonded with slow-cure epoxy — not a press fit, and not CA.
- Magnets sit `magnet_recess` (0.3 mm) below the face so bare magnet never touches the camera, and are backed by `magnet_back` (0.8 mm) of PETG.
- **The pockets are deeper than the floor**, so the SCAD raises a local backing pad inside the shell and deepens the cavity by the same amount. `inner_h` therefore means clear height *above* the pads; the outer height grew ~1.5 mm as a result. If you change `magnet_t`, the shell height follows automatically.
- **Polarity is irrelevant** against a plain steel shim — any orientation attracts. That removes an entire class of assembly error, and is a good reason to prefer a shim over magnets on both halves.
- Keep the magnets away from the PM motor in the camera base and the shutter solenoid in the lens housing. **Re-shoot a test frame after mounting** to confirm exposure hasn't shifted.
- **The magnets must beat the pogo pins' spring force**, which is 100–300 g for two pins trying to push the pack off. Test holding force with the pins fitted and compressed, never on a bare shell.
- `mount_holes` still supports screwing through the floor instead, if a film-door-safe location is ever confirmed.

### Print and assembly order

- Print the base floor-down. The magnet pockets then open at the bed and their ceilings bridge ~6 mm, which PETG handles.
- **Inserts first, then magnets.** Both involve heat; melting inserts in next to cured epoxy risks softening the bond.
- Check the four backing pads clear your actual parts before printing — they intrude into the bays. The default placement keeps them out of the divider and the screw bosses, but they do sit under the battery.

---

## Option A — 4× regulated 1.5 V AAA

Four [XTAR 1.5 V AAA cells](https://www.xtar.cc/product/xtar-aaa-lithium-1620mwh-battery.html) (1620 mWh / 1000 mAh, 1200+ cycles, 1.9 h charge) in series give a flat 6.0 V with no converter and no charge circuit — the BOM drops to a holder, C1, R1, a switch and the JST lead. ~6.5 Wh, roughly 2.5× Option B.

**Gating spec:** the datasheet curve is labelled 2 A max per cell, which caps the whole series string at 2 A. If the motor's peak exceeds that, an internal converter may fold back or hiccup mid-cycle — an intermittent stall rather than an obvious fault.

Other trade-offs:

- Charging moves off-camera (XTAR charger).
- Regulated cells hold 1.5 V then drop off a cliff at cutoff — no sagging warning. Keep a matched spare set.
- Still a stiff, low-impedance source: **keep C1 and R1**.
- Charge and rotate the four cells as a matched set; a mismatched string collapses when the first cell cuts out.

---

## Bring-up checklist

See [testing.md](testing.md) for the full procedure and the two measurements that decide the architecture.

---

## Open items

Mirrors *Open questions* in the [README](../README.md). Ordered by what blocks what.

**Blocking — nothing downstream can be finalised without these**

- [ ] **Are the base-plate contacts a real power rail, or a high-impedance test tap?** [testing.md step 0](testing.md). If they collapse under load the whole pogo-pin interface has to move.
- [ ] Camera floor voltage and motor peak current — these choose Option A or B. [testing.md 1–2](testing.md)

**Blocking the enclosure**

- [ ] Contact spacing on the base plate, and the barrel diameter of the pogo pins actually bought → `pogo_spacing`, `pogo_body_d`.
- [ ] Measure actual part envelopes and update the SCAD bay parameters.
- [ ] Mounting location on the camera base that clears the film door and keeps magnets off the motor and shutter solenoid.
- [ ] Magnet holding force tested with the pogo pins fitted and compressed, not on a bare shell.

**Design decisions still open**

- [ ] Does Option A need D1 as well? Both options now sit on the same rail as the film-pack battery, so the backfeed case looks identical, but only Option B's BOM carries the Schottky.
- [ ] R1 final value, after the shunt measurement — and remember to subtract the pogo pins' own contact resistance.

---

## Changelog

**Unreleased**

- **U3 is now the TPS630702 buck-boost** on the carrier PCB, replacing the Pololu D30V33MALCMA (kept as U3-alt). Holds 6 V across the whole 2S range, ~$0.90 against ~$35, and shrank Option B from 92 × 58 to **86 × 50 mm**.
- **C1 split into C1a/C1b, 2 × 220 µF** (440 µF): the TPS630702 allows at most 470 µF on VOUT. Option A keeps 1000 µF.
- **F1 (1812L075 PPTC) added** after R1, as the backstop for force-charging a film-pack battery.
- Carrier PCB placed in KiCad (`hardware/pcb/sx70_carrier.kicad_pcb`); DRC shows the lane is over-subscribed — see [pcb.md §3b](pcb.md#3b-kicad-project--and-what-drc-found).

**v0.4 — 23 Sept 2026**

- **Carrier PCB added.** The pogo pins, C1, D1, R1, SW1 and the battery connectors move onto one 2-layer board, with the modules mounted to it. Loose modules on flying leads were wrong for a 2 A path with a 0.7 mm-stroke pin whose position has to be accurate.
- **Camera constraints recorded**: bottom width **95 mm** (hard ceiling), contact spacing **~50 mm** (provisional). The 50 mm span exceeded the old electronics bay, forcing an **L-shaped board** — a full-length lane carrying both pins, plus a main body under the modules.
- **The battery moved off the board** onto the case floor beside it, which is what keeps the pack thin.
- **P1 reverted to the through-hole pin** (7982-1, $1.55) from the solder cup (7983-1, $1.90). The cup only made sense with no board to solder to.
- **J2 (pack power) and J3 (balance tap) added** — the battery had no defined connection at all. Both JST-XH, because PH's 2 A rating is exactly the current drawn.
- **J1 dropped.** It survived the pogo-pin change as a bench output for the dummy pack, but it was the one part with no required role, and it carried 2 A on a 2 A connector. The dummy pack can be fed from the bench supply as before.
- Envelope **92 × 58 × 17.7 mm**, inside the 95 mm limit and 1 mm thinner than v0.3. Layout verified collision-free by `scripts/layout_svg.py`.

**v0.3 — 23 Sept 2026**

- **Camera interface changed to pogo pins** on the base-plate contacts, replacing a JST-PH pigtail soldered to the traces feeding the film-chamber contacts. The solder route meant a 350 °C iron on 50-year-old flex whose adhesive releases under heat; bench 1-B lifted pads and traces at 415 °C. J1 is retained as a bench output only. Added: ≥3 A pin rating, gold plating, the pins' contact resistance counting against R1, and spring force working against the magnets.
- **Enclosure fixings changed to M2.5 brass heat-set inserts** from M2 self-tapping screws — this pack gets opened repeatedly during bring-up.
- **Magnet mounting detailed**: 4× 6 × 2 mm discs epoxied into pockets on the camera-facing face, against a VHB-bonded steel shim. Polarity is irrelevant against plain steel.
- **Shell height is now set by internal bosses.** Magnet pockets are deeper than the floor and pogo pins need grip length, so `inner_h` means clear height *above* the bosses and the cavity deepens automatically. Option B grew to ~88 × 40 × 19 mm.
- **Balancing section expanded** — the protection board does not balance, and passive balancing only runs during the CV taper.
- **testing.md step 0 added**: confirm the base-plate contacts are a real power rail, not a high-impedance test tap. Everything rests on it.
- Replacement flex routes and PCBWay order prep split into [flex-order.md](flex-order.md); lens-flex reverse-engineering workspace added under `hardware/flex-lens/`.

**v0.2** — two architectures carried in parallel (Option A 4× AAA, Option B 2S LiPo); fine-adjust regulator with low-voltage cutoff replaced the fixed 6 V module.

**v0.1** — initial 2S LiPo design, fixed 6 V Pololu D24V22F6, soldered pigtail.

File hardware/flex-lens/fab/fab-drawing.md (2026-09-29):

# Fabrication Drawing — Lens / Shutter Flex

The fab drawing is where flex orders succeed or fail. Gerbers describe copper; they say nothing about coverlay, stiffeners, bend zones or copper type, and **all of those are quoted and built from the drawing.** Export it as a PDF alongside the Gerbers.

## Drawing checklist

- [ ] Overall dimensions, with tolerances (±0.1 mm on outline is typical; tighten only where it matters)
- [ ] Stackup cross-section: base PI, copper, coverlay, adhesive — with thicknesses
- [ ] Stiffener outlines, dimensioned, with material and thickness called out per location
- [ ] Coverlay openings (state that `F.Mask`/`B.Mask` in the Gerbers *are* the coverlay openings)
- [ ] Bend zones hatched, with bend axis and minimum bend radius for each
- [ ] Copper type callout — RA vs ED
- [ ] Surface finish
- [ ] Any gold-finger or sliding-contact areas, with plating spec
- [ ] Layer-to-outline registration datum
- [ ] Revision, date, part name, camera body it fits

## Notes block — paste onto the drawing

Edit the bracketed values once the design is measured.

```
NOTES:

1.  MATERIAL: POLYIMIDE FLEX, [1] LAYER, FINISHED THICKNESS [0.12] mm.
2.  COPPER: [0.5] oz, ROLLED ANNEALED (RA). ED COPPER IS NOT ACCEPTABLE —
    THIS PART IS FOLDED IN SERVICE.
3.  COVERLAY: POLYIMIDE, BOTH SIDES UNLESS NOTED. THE SOLDERMASK LAYERS IN
    THE SUPPLIED GERBERS DEFINE THE COVERLAY OPENINGS.
4.  SURFACE FINISH: ENIG.
5.  STIFFENER: [FR4 / POLYIMIDE], [0.2] mm, LOCATIONS PER DRAWING, BONDED
    TO THE [BOTTOM] SIDE.
6.  BEND ZONES ARE HATCHED. MINIMUM BEND RADIUS [1.2] mm.
    NO PLATED HOLES OR VIAS PERMITTED IN BEND ZONES.
    COPPER IS SINGLE-LAYER THROUGH ALL BEND ZONES.
7.  OUTLINE PROFILED PER EDGE.CUTS LAYER. OUTLINE TOLERANCE ±0.1 mm.
8.  NO ADHESIVE SQUEEZE-OUT INTO COVERLAY OPENINGS OR BEND ZONES.
9.  PART SHIPS FLAT. DO NOT CREASE OR FOLD FOR PACKAGING.
10. SAMPLE FIT-CHECK ARTICLE REQUESTED BEFORE FULL RUN.
```

Note 9 is not boilerplate — a creased flex arrives pre-damaged, and it happens.

## PCBWay order comment — draft

Paste into the order notes. Flex orders get human review and an unfamiliar outline draws questions; answering them up front saves a round trip.

```
This is a replacement flexible circuit for a vintage camera (Polaroid SX-70
lens/shutter assembly), reverse-engineered from the original part.

Key points:
- The part is FOLDED IN SERVICE, not static. Please use rolled-annealed (RA)
  copper. Bend zones are marked on the fab drawing with a minimum radius.
- Coverlay openings are defined by the soldermask layers in the Gerbers.
- Stiffener locations, material and thickness are on the fab drawing.
- The outline is irregular by design — it follows the original part. Please
  profile exactly to the Edge.Cuts layer.

Please confirm before starting:
1. Minimum trace/space you can hold on this stackup.
2. That RA copper is available at the requested weight.
3. Achievable outline tolerance.

Happy to supply the original part scan if it helps.
```

## Pre-fab gate

**Laser-cut a paper test piece from the outline and check it fits the body before ordering copper.** Cheap, fast, and catches a scale error — which is the standard way a scan-traced part goes wrong.

## Spec sheet

Fill in, then mirror into the PCBWay quote form.

| Parameter | Value |
|---|---|
| Layers | |
| Base PI thickness | |
| Finished thickness | |
| Copper weight | |
| Copper type | RA (required — part folds) |
| Coverlay | Polyimide, colour: |
| Stiffener material / thickness | |
| Stiffener locations | |
| Surface finish | ENIG |
| Silkscreen | |
| Outline tolerance | |
| Min bend radius | |
| Quantity | |

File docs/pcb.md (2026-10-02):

# Carrier PCB — PCB1

Single 2-layer board carrying the pogo pins, the output path (C1, D1, R1), the switch, the battery connectors, the IP2326 module and the TPS630702 regulator. Only the cells and the 2S protection board stay off-board on wires.

**Status: placed, not routed.** `hardware/pcb/sx70_carrier.kicad_pcb` is generated from [scripts/build_kicad_pcb.py](../scripts/build_kicad_pcb.py), with outline, holes and footprints but no netlist or copper. KiCad DRC found the placement does not fit as drawn; see [§3b](#3b-kicad-project--and-what-drc-found) before relying on any position below.

---

## 1. Constraints that set the shape

| Constraint | Value | Source |
|---|---|---|
| Camera bottom max width | **95 mm** | Measured. The pack's long axis must fit inside this |
| Pogo pin spacing | **~50 mm** | Provisional — to be confirmed on the next camera opened |
| Pin protrusion | 1.0 mm past the outer face | Set by the 2.6 mm PCB standoff |
| Pin stroke | 0.7 mm | Mill-Max 7982-1 datasheet |

**The 50 mm spacing is what drives the architecture.** It is larger than the old 46 mm electronics bay, so the pins cannot both live in it. They have to be placed against the whole shell, which puts one of them under the battery region — hence the L-shaped board below.

It also kills the idea of lengthening the shell to ~105 mm to make room: 95 mm is the ceiling. (The pack was 92 mm before the TPS630702 replaced the Pololu module; it is 86 mm now.) The *other* axis runs along the camera's ~170 mm length and can grow freely, which is where the extra width comes from.

---

## 2. Shape and why

An **L**: a full-length **lane** along one edge carrying both pogo pins and the output-path parts, plus a **main body** under the IP2326 module and the regulator.

```
 y (mm, shell outer coords)                       outer 86 x 50 x 17.7
 47 +------------------------------------------------+ PCB
    |                    |  main body x 46-83          |
    |   battery sits on  |  +-------------------------+|
    |   the CASE FLOOR   |  | TPS630702 |   IP2326    ||
    |   beside the PCB   |  +-------------------------+|
 13 +--------------------+-----------------------------+
    | J3 P1a SW1/J2 C1a C1b D1 R1 F1  P1b  J4          |  <- lane, y 3-13
  3 +--------------------------------------------------+
    3                                                83   x
```

The lane sits at PCB height (2.6–4.2 mm above the inner floor). The battery does **not** stack on the board — it sits on the case floor beside the main body, which is what keeps the pack thin. That is the whole reason for the L.

**C1 (C1a + C1b) lives in the lane between the two pins on purpose.** Its job is supplying motor inrush; putting it in the passive column on the far side of the board would have added exactly the loop inductance that defeats it.

---

## 3. Placement

Shell outer **86 × 50 mm**, cavity 82 × 46, PCB inset 1 mm from the cavity. Coordinates are shell outer, origin at the outside corner — board-local positions in the scripts + 3 mm. This is the placement DRC rejected (§3b).

| Ref | Part | Centre (x, y) | Footprint | Notes |
|---|---|---|---|---|
| P1a | Mill-Max 7982-1 pogo | **21, 10** | 2.1 dia | **Underside mount**, soldertail up through the board |
| P1b | Mill-Max 7982-1 pogo | **71, 10** | 2.1 dia | 50 mm from P1a. Both shifted 3 mm right of centre so J3 and a mounting hole fit at the lane's left end |
| C1a, C1b | 220 µF 10 V polymer (440 µF total) | 36, 8 and 45, 8 | 6.3 dia can | Between the pins — shortest inrush loop. TPS630702 allows 470 µF max on VOUT |
| D1 | SS34 | 52, 8 | SMC | DO-214AB |
| R1 | Power resistor | 59, 8 | 2512 | Value from bench data |
| F1 | Littelfuse 1812L075 PPTC | 64.5, 8 | 1812 | After R1, before P1a |
| SW1 | SPDT slide | 27.5, 5 | 7 × 4 | Actuator faces the −y wall |
| **J2** | **Pack power in, JST-XH 2-pin** | **28, 10** | 8 × 6 | From the protection board's P+/P−, **not** the cells. ~2 A |
| **J3** | **Balance tap, JST-XH 3-pin** | **13.5, 9** | 11 × 6 | B−, midpoint, B+. Midpoint feeds the IP2326 **BM** pad |
| J4 | 5-way link to U2 | 78, 9 | 1×5 2.54 mm | |
| U2 | IP2326 module | 67.5, 23 | **31 × 18** | Measured from vendor drawing. USB-C faces the +x end wall |
| U3 | TPS630702 buck-boost block | ~55.5, 40 | ~15 × 12 | QFN + L1 + Cin/Cout + FB divider, on-board. Replaces the $35 Pololu module. IC itself at 50, 39 |
| — | Battery, on the **case floor** | 21.5, 29 | 35 × 26 | Not on the board |

PCB outline: lane `x 3–83, y 3–13`; main body `x 46–83, y 13–47`. Radius the internal corner at (46, 13) — it is a stress riser otherwise.

[scripts/layout_svg.py](../scripts/layout_svg.py) finds no part body fouling a lid-screw boss, a magnet pocket or another part. It compares body rectangles only; courtyards do overlap (§3b). Parts on the board clear the 1.5 mm magnet pads because the 2.6 mm standoff passes over them.

### Why the pins mount on the underside

The plungers point down through the case floor. Body on the bottom face, soldertail up through a hole, soldered on top. The body then extends 5.2 mm below the board: from 2.6 mm above the floor down to 1.0 mm past the outer face. That is exactly the protrusion target.

**Confirm the soldertail hole size from the 7982-1 datasheet before drawing the footprint.** The related 0906 series uses a 0.020″ (0.51 mm) mounting hole; do not assume it carries over.

### Height budget

| | mm |
|---|---|
| Case floor | 1.6 |
| Standoff to PCB underside | 2.6 |
| PCB | 1.6 |
| Tallest part (allowance) | 10.0 |
| **Total** | **15.8** |
| Interior ceiling | 16.1 |

0.3 mm of headroom. The 10 mm allowance was set by the old 1000 µF C1. The 6.3 × 5.3 mm cans of C1a/C1b no longer set it, so **check the real height of the tallest part — the vertical JST-XH headers and U2 on its standoffs — against it before ordering.**

---

## 3a. Board-level layout

Plan view: **[../hardware/bom/PCB1-carrier/pcb-layout.svg](../hardware/bom/PCB1-carrier/pcb-layout.svg)**, generated by [scripts/pcb_svg.py](../scripts/pcb_svg.py). That script finds no body, hole or outline clashes, but KiCad's courtyard check does (§3b).

Board is **80 × 44 mm**, L-shaped, origin bottom-left, inset 1 mm from the cavity — so board-local + 3 mm = shell coordinates.

### Headers and connectors

| Ref | Type | Goes to |
|---|---|---|
| **J2** | JST-XH 2-pin | Pack power, from U1 protection board `P+`/`P−` |
| **J3** | JST-XH 3-pin | Balance tap: `B−`, midpoint, `B+`. Midpoint feeds U2's `BM` |
| **J4** | 5-way link | The IP2326 module: `VIN+`, `GND`, `B+`, `B−`, `BM` |
| SW1 | SPDT slide | In series with the R6/R7 top leg, so off also removes the 9.3 µA divider draw |

There is deliberately **no output connector** — the pogo pins are the output, and J1 was dropped.

### Zones

- **Lane, y 0–10, full length.** Both pogo pins, C1a/C1b, D1, R1, F1, plus J2, J3, SW1 and J4. Nothing tall, because the battery passes over it in the shell.
- **Main body, x 43–80, y 10–44.** U2 on standoffs over its four dashed mounting holes, and the regulator block: U3, L1, Cin, Cout, the FB divider, and the three signal additions — Q1, the interlock divider and the EN undervoltage divider.

Four M2 holes at (3, 3), (77, 3), (45.5, 41.5), (77, 41.5) carry the board on 2.6 mm standoffs.

---

## 3b. KiCad project — and what DRC found

`hardware/pcb/sx70_carrier.kicad_pcb`, generated by [scripts/build_kicad_pcb.py](../scripts/build_kicad_pcb.py) using KiCad 10's bundled `pcbnew`. Outline, mounting holes and 34 footprints placed; nothing routed, no netlist yet. It loads cleanly and renders to `sx70_carrier-top.svg`.

**DRC reports 15 courtyard overlaps, and they are real.** The SVG checker in `scripts/layout_svg.py` compares component *body* rectangles. KiCad compares **courtyards**, which include pad extents and clearance and are materially larger. The placement that looked clean is not.

Overlapping pairs: C1a/C1b, C1a/J2, J2/SW1, J3/P1a, C1b/D1, D1/R1, F1/R1, H2/J4, C5/H3, plus the 0603 pairs at 2.5 mm pitch (R2/R3, R4/R5, R6/R7, C5/C6, C2/C3/C4).

**The lane is over-subscribed.** Summing courtyard widths for everything currently in it — J3, P1a, SW1, J2, C1a, C1b, D1, R1, F1, P1b, J4 — comes to roughly 81 mm before gaps, on an 80 mm board. It does not fit, and no amount of nudging fixes that.

**The fix is structural, not cosmetic:**

- **Keep only the output path in the lane**: P1a, C1a, C1b, D1, R1, F1, P1b.
- **Move the connectors into the main body**: J2, J3, J4 and SW1. SW1 can take the main body's +y edge, which is also a shell wall, so the actuator still reaches.
- **Widen the lane** from 10 mm to about 13 mm for the electrolytics plus courtyard.
- **Space 0603 pairs at 3.5 mm**, not 2.5 mm.

**This reopens the board size.** The main body is already carrying U2 at 31 × 18 plus the regulator block, so absorbing four connectors needs more area. There is 9 mm of length headroom before the 95 mm camera limit, and width is comparatively free — but the 86 × 50 figure will grow. Decide how much to give back before re-placing.

Smaller footprints would claw some of it back: a 220 µF polymer in a 7343 D-case instead of a 6.3 mm can, and 0402 for the dividers.

Other DRC output is expected at this stage: clearance and solder-mask items come from every pad sitting on no net, and resolve once a netlist is imported.

---

## 4. Nets and copper

Peak is ~2 A. IPC-2221 for external 1 oz copper at 10 °C rise gives ~0.75 mm for 2 A; specify **1.5 mm minimum** on the power path for margin, and pour where possible.

| Net | Path | Width |
|---|---|---|
| VBAT+ | **J2** → U3 VIN, and U2 charge return | 1.5 mm (~2 A in) |
| BM | **J3** centre pin → U2 BM pad | 0.5 mm |
| VOUT → V6 | U3 VOUT → C1a/C1b → D1 → R1 → F1 → **P1a** | **1.5 mm min, pour preferred** |
| GND | pour both layers, stitched | pour → **P1b** |
| CHG | USB-C → U2 → protection → cells, BM to midpoint | 1.0 mm |
| EN | SW1 → R6/R7 divider → U3 EN (Q1 pulls low on USB) | 0.3 mm |

- **C1a/C1b go as close to the pins as routing allows.** Its job is motor inrush; distance defeats it.
- **R1 is in series with the pins.** The pins add 40 mΩ of their own and F1 adds its hold resistance — measure in circuit and subtract both before choosing R1.
- Keep the V6 run from R1 through F1 to P1a short and fat. Everything in that path is source impedance you did not intend.

---

## 5. Fab

| | |
|---|---|
| Layers | 2 |
| Thickness | 1.6 mm |
| Copper | 1 oz |
| Finish | ENIG (gold pads under the pogo solder joints) |
| Min trace/space | 0.2 / 0.2 mm — inside PCBWay's standard 2-layer capability |
| Min hole | 0.3 mm |
| Outline | L-shape per above; radius the internal corner to avoid a stress riser |
| Vendor | PCBWay, same account as the flex orders |

---

## 5a. Battery connections

The pack needs **two** connections to the board, not one.

- **J2 — pack power.** From the 2S protection board's **P+/P−**, never straight off the cells, so the BMS guards both charge and discharge. Carries ~2 A.
- **J3 — balance tap.** The 3-wire balance lead: B−, midpoint, B+. The **midpoint feeds the IP2326's BM pad**, which is the only thing doing any cell balancing — the protection board does not balance. Bringing the whole lead to a standard JST-XH 3-pin also keeps the recovery path: a hobby charger can top-balance a drifted pack or set a 3.8 V/cell storage charge far faster than BM will.

**Connector current rating is a real constraint here.** JST-PH is rated 2 A, and the pack path draws ~2 A — right at the limit. JST-XH is rated 3 A in the same rough size, so both J2 and J3 use XH.

Note J3 taps the cells ahead of the protection board, as balance leads always do — an external charger plugged in there bypasses the BMS. That is normal hobby practice, but it is worth knowing before handing the connector to someone else.

---

## 6. Open

- [ ] **Confirm the 50 mm pin spacing** on the next camera opened. Every dimension here follows from it.
- [ ] Soldertail hole diameter for 7982-1, from the datasheet.
- [ ] Module attachment: headers or castellated pads. Headers cost height the budget has little of.
- [ ] SW1 actuator reach across the 1 mm board-to-wall gap plus the 2 mm wall.
- [ ] Does Option A need D1 too? Same rail, same backfeed case — see the README.
- [ ] R1 final value, after the shunt measurement.

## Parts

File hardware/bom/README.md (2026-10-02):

# Bills of Materials

```
bom-option-a-aaa.csv    Option A — 4x regulated 1.5 V AAA
bom-option-b-lipo.csv   Option B — 2S LiPo + USB-C charger + adjustable buck
digikey-order.csv       Consolidated Digi-Key line items across pack, flex and bench
<ref>-<part>/           Reference material per part
```

## Per-part directories

One directory per BOM reference, holding whatever was gathered while sourcing it: vendor photos, datasheets, dimension drawings, screenshots of listings, and a `notes.md` recording what was actually verified versus assumed.

Listings vanish and vendors swap revisions without changing the listing, so anything that settled a decision gets saved here rather than linked.

| Directory | Ref | Part |
|---|---|---|
| `U1-2s-protection/` | U1 | 2S protection board (DW01/8205-class) |
| `U2-ip2326-charger/` | U2 | IP2326 USB-C 2S charger module |
| `U3-pololu-d30v33/` | U3-alt | Pololu D30V33MALCMA fine-adjust buck (fallback; U3 is the TPS630702 on PCB1) |
| `B1-lipo-2s/` | B1 | 2S LiPo pack |
| `P1-pogo-millmax-7982/` | P1 | Mill-Max 7982-1 spring-loaded pins |
| `PCB1-carrier/` | PCB1 | Carrier PCB — see [docs/pcb.md](../../docs/pcb.md) |
| `enclosure-hardware/` | — | Inserts, screws, magnets, steel shim |

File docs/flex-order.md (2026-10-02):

# Replacement Flex — PCBWay Order Prep

Why this lives in the battery project: it started as risk mitigation. The original plan soldered a pigtail onto the traces feeding the film-chamber battery contacts, and 50-year-old flex adhesive releases almost immediately under heat — bench 1-B lifted pads and traces on the first switch at 415 °C.

**As of v0.3 the pack uses pogo pins and solders nothing to the camera, so that risk is gone.** What remains is the ordinary problem: these flexes disintegrate with age and handling regardless. Parts are already ordered (below), so this is now insurance and a standing reference rather than a dependency of the battery project. Full background in the SX-70 Repair Notes, *Flex circuit and soldering* → *Disintegrating flex and replacement options*.

---

## 1. First gate: which flex, and which motor chip?

Nothing below can be decided without these two answers.

- **Body flex** — connects S3, S5, S6, S7, S8, S9, the battery and the lensboard, and carries the motor driver.
  - **Later style, DIP-8 MCM** (SN28648P, Polaroid p/n 705982): solved, see Route A.
  - **Early Model 1, TO-5 metal-can MCC**: Cundari's board is DIP-8. Either jumper the MCC connections to the matching flex pads, or upgrade to the DIP-8 chip using his [replacement motor control chip](https://www.pcbway.com/project/shareproject/Polaroid_SX70_Motor_Control_Chip_Replacement_8_pin_DIP_version_13df00a5.html).
- **Lens / shutter flex** — **no open-source design exists.** The only commercial source found is PolaStudio ($50, sold out as of Sept 2026). This one means Route C: reverse-engineering.

**Scan the failing flex at maximum resolution before any further handling**, whichever route you take. The substrate keeps degrading and the geometry is unrecoverable once it crumbles.

---

## 2. Route A — Cundari's open-source body flex (no document prep)

[Polaroid SX70 Body Flex](https://www.pcbway.com/project/shareproject/Polaroid_SX70_Body_Flex_1d4fced3.html), CC BY-SA. **Order directly from the share page — there is an Add to cart button and the Gerbers are downloadable (`SX70_Flex_2025-12-09.zip`).** You prepare nothing.

Its published build:

| Parameter | Value |
|---|---|
| Layers | 2 |
| Finished thickness | 0.12 mm |
| Copper weight | 0.5 oz |

Fits both Model 1 and alpha-style motor connectors. The designer's warning is worth repeating: **do not make hard creased folds** when bending it around the body, or the copper breaks.

**Both parts ordered from PCBWay, Sept 2026.** The body flex shipped; the motor control chips were quoted at an 18–20 day build.

| | |
|---|---|
| Body flex | Cundari's published Gerbers, built to the share page's defaults |
| Motor control chip | **10 assembled boards, ~$135 the lot** — roughly a third boards, a third components, a third assembly |

> Order numbers, exact prices, dates and vendor correspondence live in the gitignored `private/` folder, not here. A reader reproducing this needs the part sources and the ballpark, not the buyer's account details.

⚠️ **The build window overlaps the Chinese holidays.** The quote email linked PCBWay's *Holiday Schedule of Mid-Autumn Festival & National Day 2026*, and both fall inside an 18–20 day build placed in late September. Check that schedule before assuming the quoted date.

**Keep the PCBA quotation BOM.** It is the only record of which components PCBWay actually fits — which matters for a replacement for an obsolete SN28648P, where substitutions change the part.

**Pins are a separate order.** The board is 10 × 10 mm, 1.0 mm thick, with SMT parts on the board and **through-hole pins into the flex** — 5 pins, the DIP-8 pattern with 3 unpopulated, matching the original MCM's 5 populated legs. The [GitHub BOM](https://github.com/fotocundari/SX70-Motor-Control-Chip) specifies making them from the legs of **Stackpole JW60ZT0R00** tin-plated 0 Ω through-hole jumper resistors (22 AWG), stocked by Digi-Key and Mouser.

Two cautions: the PCBWay page's wording — "requires adding jumper wires to replace pins" — contradicts the GitHub BOM, which is the more specific and more recent source; and **check the PCBA quotation BOM before ordering pins separately**, since the quoted component line may already cover them.

**Record the as-built fab parameters at the time of ordering.** PCBWay's notification emails carry only the product number and filename, so material, copper weight, thickness and finish exist solely on the order management page — and the page ages out. Without them the build is not reproducible.

| Parameter | As built (fill from order page) |
|---|---|
| Layers | |
| Finished thickness | |
| Copper weight | |
| Copper type | |
| Coverlay | |
| Stiffener | |
| Surface finish | |
| Quantity | |

## 3. Route B — buy finished

[PolaStudio](https://polastudio.online/products/polaroid-sx70-sonar-680-electronic-flex-repair-tools): lens flex $50, body flex $100 (includes a new MCM). Both sold out as of Sept 2026; email about restock. No fabrication, no prep.

## 4. Route C — reverse-engineer an original

Required for the lens/shutter flex, optional for a body flex you want dimensionally identical to the original. The established workflow:

1. **Scan the original flat** at maximum optical resolution with a dimensional reference in frame. Do this first, before handling degrades it further.
2. **Trace to vector.** Corel was used in the OpenSX70 write-up; any vector tool works.
3. **Import into EDA** as DXF for the outline, then lay out copper against the scan.
4. **Laser-cut a paper test piece** and check fit in the body *before* spending money on fab.
5. **Fab at PCBWay.**

Worth doing what Cundari did: add pads for the Mabuchi motors repair shops fit, rather than reproducing the original exactly.

**Tooling note: KiCad is currently in this machine's Trash.** Reinstall before starting; it handles this fine.

---

## 5. PCBWay flex order parameters

Fill this in per order. Applies to Route C, and to changing the build options on Route A.

| Parameter | Value | Notes |
|---|---|---|
| Layers | | 1 or 2 |
| Base PI thickness | | PCBWay standard: 0.025 / 0.05 mm (1-layer), 0.08 mm (2-layer) |
| Finished thickness | | Cundari's body flex: 0.12 mm |
| Copper weight | | 0.25 oz (9 µm) up to 2 oz (70 µm); 0.5 oz on the reference design |
| Coverlay | | Polyimide coverlay, not LPI solder mask — specify colour and openings |
| Stiffener: material | | FR4, polyimide, or stainless steel |
| Stiffener: thickness | | FR4 offered 0.2 / 0.4 / 0.5 / 0.6 / 0.8 / 1.0 / 1.2 / 1.5 mm |
| Stiffener: locations | | **Call out on the fab drawing.** Needed under connector and solder-pad areas |
| Surface finish | | ENIG is the usual choice for flex |
| Silkscreen | | Optional legend |
| EMI shielding film | | Optional; not needed here |
| Outline / profiling | | Laser or die cut — the outline layer must be exact |
| Bend areas + min radius | | Annotate. No traces crossing a fold perpendicular if avoidable |
| Quantity | | |

**Confirm minimum trace/space and minimum hole size against PCBWay's live quote form** — I have not verified the current flex figures, and they differ from their rigid-PCB values.

### Materials PCBWay actually offers

Verified from their FPC stackup and flex capability pages, Sept 2026.

| Category | Options |
|---|---|
| Base | **Polyimide (PI)**, 12.5 µm (0.5 mil) to 125 µm (5 mil), with or without adhesive. Dk 3.5 adhesive / 3.3 adhesiveless. **PET (transparent)** also offered |
| Copper weight | Raw 9 / 12 / 18 / 35 / 50 / 70 / 88 µm; finished 15–88 µm. Flex portion 0.5–2 oz finished, 4 oz max |
| Copper type | **Not stated anywhere on their public pages — you must ask.** See below |
| Coverlay | Polyimide. Yellow (standard), black, white (thicker, 31–43 µm PI). 12.5–43 µm PI backing + 12.5–50 µm adhesive |
| Stiffener | PI, FR4 (0.2 / 0.4 / 0.5 / 0.6 / 0.8 / 1.0 / 1.2 / 1.5 mm), stainless steel. Thickness tol ±10% |
| Surface finish | HASL, **ENIG**, ENEPIG, electrolytic Ni/Au, soft gold, hard gold, immersion silver, immersion tin, OSP |
| Layers | Flex 1–12; rigid-flex up to 26 |
| Thickness tolerance | ±1.0 mil single-layer; ±1.2 mil multilayer up to 12 mil |
| Max order qty | 3000 |

Multilayer adhesiveless stackups use 13 µm "pure gum" spacers on inner layers.

**The copper-type gap matters.** PCBWay's public pages never distinguish rolled-annealed from electrodeposited, so the standard flex process gives you whatever is standard — and ED copper cracks in a part that folds. For any SX-70 flex, RA has to be requested explicitly and confirmed in writing. This applies to the body flex as much as the lens flex: Cundari's own warning is not to make hard creased folds when bending his board around the body.

## 6. Files to submit

- **Gerbers**, RS-274X, one per layer, including the board outline on its own layer.
- **Excellon drill** file, if there are any holes or vias.
- **Fabrication drawing (PDF)** — this is where flex orders are won or lost. It must show:
  - Overall dimensions and tolerances
  - Stackup: base PI, copper, coverlay, adhesive
  - Stiffener locations, materials and thicknesses
  - Coverlay openings
  - Bend areas and minimum bend radius
  - Surface finish and any gold-finger/contact plating
- A note in the order comments describing what the part is. Flex orders get human review, and an unusual outline draws questions.

---

## 7. Open

- [x] Which flex is being replaced — **lens / shutter**. Route C, workspace in [../hardware/flex-lens/](../hardware/flex-lens/).
- [ ] Which motor chip is in the target body — TO-5 MCC or DIP-8 MCM?
- [ ] Did the Sept 2026 PCBWay quote come back?
- [ ] Target camera confirmed (1-A / 1-B / 1-C / Model 2)?

---

## 8. Links

**Nick Cundari — designs used here**

- [Polaroid SX70 Body Flex (PCBWay)](https://www.pcbway.com/project/shareproject/Polaroid_SX70_Body_Flex_1d4fced3.html) — replacement body flex. Gerbers downloadable, orderable directly from the page. CC BY-SA
- [SX70 Motor Control Chip Replacement, 8-pin DIP (PCBWay)](https://www.pcbway.com/project/shareproject/Polaroid_SX70_Motor_Control_Chip_Replacement_8_pin_DIP_version_13df00a5.html) — SN28648P replacement, order page
- [GitHub — fotocundari/SX70-Motor-Control-Chip](https://github.com/fotocundari/SX70-Motor-Control-Chip) — source, Gerbers and BOM for the above. CC BY-SA 4.0. **This is where the pin spec lives**
- [GitHub — fotocundari/OpenSX70-ECM-Cundari](https://github.com/fotocundari/OpenSX70-ECM-Cundari) — his fork of the OpenSX70 ECM firmware, GPLv3

**PCBWay**

- [Flex / rigid-flex capabilities](https://www.pcbway.com/fpc-rigid-flex-pcb.html) — layer counts, copper weights, surface finishes
- [FPC stackup and materials](https://www.pcbway.com/pcb_prototype/Stack_up_for_FPC.html) — base PI thicknesses, coverlay, adhesive options
- Order management page — the **only** place a given order's as-built parameters exist

**Other sources**

- [OpenSX70 — The BodyFlex circuit](https://opensx70.com/posts/2020/19/bodyflex-1) — reverse-engineering route and body flex background
- [OpenSX70 — For Dummies part 2](https://opensx70.com/tutorials/opensx70-for-dummies-2/) — S2–S9 and the 7-way flex pinout (author flags some details as uncertain)
- [PolaStudio — SX70/Sonar/680 flex](https://polastudio.online/products/polaroid-sx70-sonar-680-electronic-flex-repair-tools) — commercial lens and body flex, sold out Sept 2026

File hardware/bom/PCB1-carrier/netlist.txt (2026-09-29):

SX-70 External Power Pack — Option B — netlist
Generated by scripts/schematic_svg.py. Reference while drawing in an EDA tool.

COMPONENTS
  BT1   2S LiPo pack, 350-500 mAh          off-board
  U1    2S protection board, DW01/8205      off-board
  J3    JST-XH 3-pin, balance tap
  J2    JST-XH 2-pin, pack power in
  U2    IP2326 charger module (Z-6732-V4.0, 2S)   on standoffs
  J4    5-way link to U2
  U3    TPS630702, adjustable buck-boost
  L1    1.5 uH shielded
  Cin   2 x 10 uF / 25 V
  Cvaux 100 nF
  Cout  3 x 22 uF / 16 V
  R2    649 k 1%          FB divider upper
  R3    100 k 1%          FB divider lower
  C1a   220 uF 10 V polymer
  C1b   220 uF 10 V polymer
  D1    SS34 Schottky
  R1    0.22-0.47 ohm 1 W
  F1    Littelfuse 1812L075 PPTC
  SW1   SPDT slide
  R6    698 k 1%          EN divider upper / soft LVC
  R7    100 k 1%          EN divider lower
  Q1    2N7002 N-MOSFET
  R4    100 k             interlock divider upper
  R5    100 k             interlock divider lower
  P1a   Mill-Max 7982-1 pogo pin, output +
  P1b   Mill-Max 7982-1 pogo pin, output -

NETS
  VBAT    U1.P+  J2.1  U2.B+  U3.VIN  Cin.1  SW1.common
  GND     U1.P-  J2.2  U2.B-  U3.GND  U3.PGND  Cin.2  Cvaux.2  Cout.2
          C1a.2  C1b.2  R3.2  R5.2  R7.2  Q1.S  P1b
  BM      BT1.BM  U1.BM  J3.2  U2.BM
  VUSB    U2.VIN+  R4.1
  SW      SW1.throw  R6.1
  EN      R6.2  R7.1  Q1.D  U3.EN
  GATE    R4.2  R5.1  Q1.G
  SWNODE1 U3.L1  L1.1
  SWNODE2 U3.L2  L1.2
  VOUT    U3.VOUT  Cout.1  C1a.1  C1b.1  R2.1  D1.anode
  FB      R2.2  R3.1  U3.FB
  VAUX    U3.VAUX  Cvaux.1
  V6A     D1.cathode  R1.1
  V6B     R1.2  F1.1
  V6      F1.2  P1a

TIED / UNUSED
  U3.PS/SYNC -> VBAT     power-save (PFM) enabled
  U3.VSEL    -> GND      output scaling unused
  U3.FB2     open        per datasheet when unused
  U3.PG      open        optional power-good LED
  U2.LED, U2.NTC  unused

NOTES
  C1a/C1b sit on VOUT, before D1/R1, so surge current still passes through R1.
  Total VOUT capacitance must stay under 470 uF (TPS63070 datasheet).
  EN is high only when SW1 is on AND VUSB is absent.
  R6/R7 also form a ~6.4 V soft undervoltage lockout via the precise EN threshold.
  R1 final value = target source impedance minus pogo pins (40 mOhm) minus F1 hold resistance.

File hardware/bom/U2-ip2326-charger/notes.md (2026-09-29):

# U2 — IP2326 USB-C 2S charger module

**Buy: the purple 2S board, `Z-6732-V4.0`.** ~$2.20 each at 10 off (AliExpress).

## Verified from vendor photos

| | |
|---|---|
| Chip | **IP2326**, marking `IP2326 / 0T41.IDA` — genuine, not a house code |
| Size | **31 × 18 mm** (from the vendor dimension drawing, not estimated) |
| Front pads | `GND`, `VIN+`, `B+`, `B−` |
| Back pads | `LED`, `NTC`, `GND`, and **`BM`** between `B−` and `B+` |
| Config points | `ISET`, `NTC`, `ROV` silkscreened on the front |
| Mechanical | 4 plated corner mounting holes; 2.2 µH inductor (`2R2`); 100 µF 16 V electrolytic |

## What matters

- **`BM` is broken out**, so balancing actually works. Many 2S modules omit it.
- **Charger only, not a BMS.** No `P+`/`P−`, no protection IC, no MOSFET pair — **U1 is still required**, and B+/B− route through U1's P+/P−.
- **Order by the 2S/3S dropdown, not by colour.** The vendor sells both configs in both colours and their photos pair black with 3S.
- **The 3S board (`LX-LSC-V2`) also has a `BM` pad** — but the IP2326 does no balancing in 3S, so it is decoration. Do not be reassured by seeing it.
- **Do not bridge `ROV`** — that is the 3S select.
- **`ISET` must be reworked** down from ~1.5 A. Identify the resistor by the silkscreen and **measure it**; several resistors share the same 3-digit codes. Floor is ~0.5 A at 180 kΩ.
- **Height risk:** the 100 µF electrolytic is the tallest part and stacks on the carrier PCB's 2.6 mm standoff, in a budget with 0.3 mm of slack. **Measure overall height before finalising the enclosure.**

## Files

| File | What it shows |
|---|---|
| `ip2326-purple-2s-z6732-v4.0-front-back.png` | The board to buy. Front and back, `BM` pad visible |
| `ip2326-dimensions-31x18mm.png` | Dimensioned drawing, 31 × 18 mm. Also shows the 3S board alongside |
| `ip2326-black-3s-lx-lsc-v2-front-back.png` | The **3S** board — wrong part, kept so it is recognisable |

## Open

- [ ] Measure overall height including the electrolytic
- [ ] Identify and measure the ISET resistor on a real board
- [ ] Confirm mounting hole positions for the carrier PCB footprint

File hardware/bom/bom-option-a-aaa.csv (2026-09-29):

ref | qty | part | spec | supplier | link | notes
B1 | 4 | XTAR AAA 1.5V Li-ion | 1620mWh / 1000mAh regulated 1.5V | XTAR | https://www.xtar.cc/product/xtar-aaa-lithium-1620mwh-battery.html | 2A max per cell — gating spec; series string = 6.0V flat
H1 | 1 | 4-cell AAA battery holder | ~46 x 46 x 12 mm | generic |  | Choose one with solder tabs
C1 | 1 | Electrolytic/polymer capacitor | 1000 uF 10 V low-ESR | generic |  | Across the string output
R1 | 1 | Power resistor | 0.22-0.47 ohm 1 W | generic |  | PolaPulse source-impedance emulation; value set by shunt data
SW1 | 1 | Slide switch SPDT | SS12D00-class | generic |  | In the positive line
P1 | 2 | Mill-Max spring-loaded pin through-hole | 7982-1-15-20-75-14-11-0; 8 A; 20 mOhm; 0.7 mm stroke; 60 g; 2.1 mm dia | Mill-Max | https://www.digikey.com/en/product-highlight/m/millmax/high-current-small-scale-spring-loaded-pins | Soldertail into PCB1; spacing must be measured; PCB standoff 2.6 mm sets protrusion
PCB1 | 1 | Carrier PCB 2-layer | carries P1 C1 R1 SW1 | PCBWay |  | Simplified version of the Option B board
- | 1 | Charger for 1.5V Li-ion AAA | XTAR mix charger or equivalent | XTAR |  | Cells charge off-camera
- | 4 | M2.5 brass heat-set insert | 3.5 mm OD x 4 mm | generic |  | Lid fixing; measure OD/length and set insert_d/insert_l
- | 4 | M2.5 x 8 mm countersunk machine screw |  | generic |  | Lid
- | 4 | Neodymium disc magnet | 6 x 2 mm N52 | generic |  | Epoxied into base pockets; polarity irrelevant vs steel shim
- | 1 | Steel shim | 0.3-0.5 mm ferrous (not stainless) | generic |  | Camera side; bond with 3M VHB
- | 1 | Slow-cure epoxy |  | generic |  | Magnet bonding; not CA (brittle in shear)

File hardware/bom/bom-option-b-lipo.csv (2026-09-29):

ref | qty | part | spec | supplier | link | notes
B1 | 1 | Gens Ace 350mAh 2S 30C LiPo | 35 x 26 x 10 mm GEA3502S30JST | HobbyEtc | https://store.hobbyetc.com/parts/view/186378 | Balance lead gives cell midpoint
U1 | 1 | 2S protection board | DW01/8205-class; overcurrent >= 5 A | generic |  | Backup to the regulator LVC
U2 | 1 | IP2326 2S USB-C charger module Z-6732-V4.0 purple | 2S variant; 31 x 18 mm; BM broken out; ISET/NTC/ROV silkscreened; 4 corner mounting holes | AliExpress |  | ~$2.20/ea at 10 off. MUST be the 2S variant - select by the 2S/3S dropdown NOT by colour; the 3S board (LX-LSC-V2) also has a BM pad but the chip does no balancing in 3S. CHARGER ONLY - no P+/P- pads so U1 is still required. Do NOT bridge ROV. ISET floor ~0.5 A
U3 | 1 | TPS630702 buck-boost (PREFERRED) | adjustable + output discharge; 2-16 V in; 2.5-9 V out; 2 A; QFN 2.5x3 | LCSC | https://www.lcsc.com/product-detail/C109322.html | TPS63070 also works (no output discharge). NOT TPS630701 - fixed 5 V. Set 6 V with R1=649k R2=100k vs 0.8 V ref. Load disconnect confirmed; 2 uA shutdown. Check measured motor peak against 2 A
R2-R3 | 2 | Feedback divider 1% E96 | 649k and 100k | generic |  | Sets TPS630702 output to 5.99 V; 8 uA divider current
Q1 | 1 | N-channel MOSFET small signal | 2N7002 or eq SOT-23 | generic |  | USB-present interlock: pulls EN low while charging
R4-R5 | 2 | Interlock divider | 100k and 100k | generic |  | VIN+ from charger module to Q1 gate
R6-R7 | 2 | EN undervoltage divider 1% E96 | 698k and 100k | generic |  | Soft LVC ~6.4 V using the precise EN threshold; SW1 in series with the top leg
U3-alt | 1 | Pololu D30V33MALCMA | 1.4-7 V out 3.8 A; adjustable LVC; 0.9 x 1.2 in | Pololu | https://www.pololu.com/product/4852 | ~$35. LVC is largely redundant with U1. Step-down so output sags near pack cutoff
C1 | 2 | Capacitor | 220 uF 10 V low-ESR polymer (440 uF total) | generic |  | Regulator output before D1/R1. TPS63070 caps VOUT capacitance at 470 uF - 1000 uF is NOT allowed
L1 | 1 | Inductor | 1.5 uH shielded (Coilcraft XFL4020-152ME or eq) | Coilcraft |  | TPS63070 power inductor
CIN | 2 | Capacitor | 10 uF 25 V X7S 0805 | generic |  | TPS63070 input
COUT | 3 | Capacitor | 22 uF 16 V X6S 0805 | generic |  | TPS63070 local output
D1 | 1 | Schottky diode | SS34 3 A 40 V DO-214AB | generic |  | Blocks film-pack battery backfeed; omit if P-FET used
R1 | 1 | Power resistor | 0.22-0.47 ohm 1 W | generic |  | Value set by shunt data; subtract F1 and pogo pin resistance
F1 | 1 | Resettable fuse PPTC 1812 | Littelfuse 1812L075; 0.75 A hold / 1.5 A trip | Littelfuse | https://www.littelfuse.com/products/fuses-overcurrent-protection/polyswitch-resettable-pptc-devices/surface-mount-polyswitch-resettable-pptc-devices/1812l/181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 | In the output path. Ends a sustained backfeed into a film-pack battery. NOT 1812L110 - its 2.2 A trip is above our 2.0 A fault
SW1 | 1 | Slide switch SPDT | SS12D00-class | generic |  | Pulls regulator EN low for off
P1 | 2 | Mill-Max spring-loaded pin through-hole | 7982-1-15-20-75-14-11-0; 8 A; 20 mOhm; 0.7 mm stroke; 60 g; 2.1 mm dia | Mill-Max | https://www.digikey.com/en/product-highlight/m/millmax/high-current-small-scale-spring-loaded-pins | Soldertail into PCB1; spacing must be measured; PCB standoff 2.6 mm sets protrusion
PCB1 | 1 | Carrier PCB 2-layer | carries P1 C1 D1 R1 SW1 J2 J3 + modules | PCBWay |  | L-shaped; see docs/pcb.md
J2 | 1 | JST-XH 2-pin header + crimp housing | 3 A rating | generic |  | Pack power from protection board P+/P-
J3 | 1 | JST-XH 3-pin header + crimp housing |  | generic |  | Balance tap; midpoint to IP2326 BM; keep reachable
- | 4 | M2.5 brass heat-set insert | 3.5 mm OD x 4 mm | generic |  | Lid fixing; measure OD/length and set insert_d/insert_l
- | 4 | M2.5 x 8 mm countersunk machine screw |  | generic |  | Lid
- | 4 | Neodymium disc magnet | 6 x 2 mm N52 | generic |  | Epoxied into base pockets; polarity irrelevant vs steel shim
- | 1 | Steel shim | 0.3-0.5 mm ferrous (not stainless) | generic |  | Camera side; bond with 3M VHB
- | 1 | Slow-cure epoxy |  | generic |  | Magnet bonding; not CA (brittle in shear)

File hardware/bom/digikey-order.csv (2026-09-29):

group | qty | part | mfr_pn | search_terms | notes
motor-control | 100 | 0 ohm TH jumper resistor — the DIP pins | JW60ZT0R00 (Stackpole) | Stackpole JW60ZT0R00 | 5 pins per board x 10 boards = 50; buy spares. Legs ARE the pins. Per the GitHub BOM, not the PCBWay page. CHECK the PCBA quote BOM first — assembly may already include them
bench | 2 | 0.1 ohm 1% 1W shunt resistor |  | current sense resistor 0.1 ohm 1% 1W | For testing.md step 1 — 100 mV/A across a scope. 0.4 W at 2 A, so 1 W minimum. 1% or the readings are meaningless
pack | 4 | Power resistor 1W — R1 candidates |  | power resistor 1W 0.1 0.22 0.33 0.47 ohm | Buy the SPREAD, not one value. R1 is set by the measured stall current; guessing wastes an order cycle
pack | 4 | 220 uF 10V low-ESR polymer capacitor |  | polymer aluminium capacitor 220uF 10V low ESR | C1a/C1b - 2 fitted (440 uF total). TPS63070 caps VOUT capacitance at 470 uF so 1000 uF is NOT allowed
pack | 5 | Schottky diode 3A 40V DO-214AB | SS34 | SS34 DO-214AB | D1. Blocks film-pack battery backfeed (one direction only - see F1)
pack | 5 | Resettable fuse PPTC 1812 0.75 A hold | 1812L075 | Littelfuse 1812L075 1812 | F1. 1.5 A trip against a 2.0 A sustained backfeed fault. Also buy 1812L110PR (DK 267851) to bracket it - 2.2 A trip is ABOVE our fault so it may never trip. Decide after measuring the motor profile
pack | 2 | SPDT slide switch |  | slide switch SPDT through hole | SW1. SS12D00 in the BOM is a generic Chinese part; C&K or E-Switch equivalent. Confirm actuator height against sw_z in the SCAD
pack | 1 | JST XH 2-pin header + housing + crimps |  | JST XH 2 position header crimp | J2. Pack power in from the protection board. 3 A rating
pack | 1 | JST XH 3-pin header + housing + crimps |  | JST XH 3 position header crimp | J3. Balance tap; midpoint feeds IP2326 BM
pack | 4 | Mill-Max spring-loaded pin through-hole | 7982-1-15-20-75-14-11-0 | Mill-Max 7982-1-15-20-75-14-11-0 | P1. 2 needed buy spares. 8 A (6.4 derated), 20 mOhm, 0.7 mm stroke, 60 g, 2.1 mm body, gold. ~$1.55 ea. Soldertail into the carrier PCB
pack-optA | 1 | 4-cell AAA battery holder with solder tabs |  | AAA battery holder 4 cell solder tab Keystone MPD | Option A only. Caliper it before setting batt_bay_l in the SCAD
flex-rework | 1 | Kester 44 Sn63Pb37 0.020" solder |  | Kester 44 63/37 .020 | Per repair notes section 4
flex-rework | 1 | Chip Quik SMD291NL tacky flux | SMD291NL | Chip Quik SMD291NL | Per repair notes section 4
flex-rework | 1 | Soder-Wick #2 rosin desoldering braid |  | Soder-Wick rosin 2 desoldering braid | Pump rather than wick on vintage flex; braid is for the replacement boards
flex-rework | 1 | 3M polyimide (Kapton) tape |  | 3M polyimide tape 5413 92 | Strain relief and flex backing. Handle by edges — skin oil weakens the adhesive
enclosure | 1 | 3M VHB tape |  | 3M VHB tape | For bonding the steel shim to the camera. Also available from McMaster

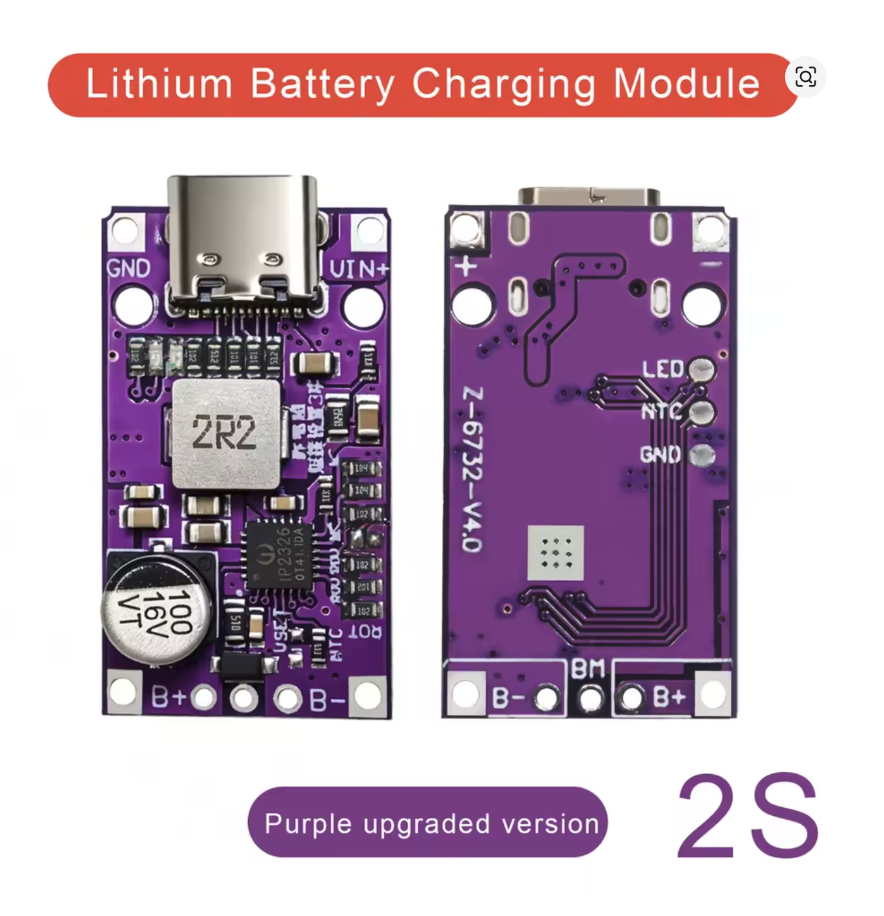
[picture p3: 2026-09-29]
hardware/bom/U2-ip2326-charger/ip2326-purple-2s-z6732-v4.0-front-back.png

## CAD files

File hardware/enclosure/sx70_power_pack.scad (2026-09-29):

// SX-70 External Power Pack — parametric enclosure
// 2S LiPo (Gens Ace 350mAh) + 2S protection board + IP2326 USB-C charger
// + Pololu 6V buck + Schottky + series R, output on 2 pogo pins to the
// camera's base-plate contacts. Most parts live on the carrier PCB — see
// docs/pcb.md; this file is the shell only.
//
// Units: mm. Print base + lid in PETG (sustained load, possible heat in a bag).
// Set `part` to "base", "lid", or "both" (preview layout).
//
// All component envelopes are generous placeholders — measure your actual
// parts with calipers and update the /* [Bays] */ and /* [Cutouts] */ values.

/* [Render] */
part = "both";            // [base, lid, both]
// Which power architecture this shell is for:
//   "lipo" = 2S LiPo + charger + buck regulator
//   "aaa4" = 4x XTAR 1.5V regulated AAA in series, no converter
battery_option = "lipo";  // [lipo, aaa4]
$fn  = 48;

/* [Shell] */
wall       = 2.0;
floor_t    = 1.6;         // mounting face thickness
lid_t      = 1.6;
// Clear height needed ABOVE the magnet backing pads (LiPo 10 + BMS ~2.5;
// AAA holder ~12). The cavity is deepened automatically to keep this clear.
inner_h    = (battery_option == "aaa4") ? 14.0 : 13.0;
corner_r   = 3.0;
clearance  = 0.2;         // lid lip fit

/* [Bays] */
// aaa4: 4-cell AAA holder (~46 x 46 x 12); electronics bay holds only the cap,
//       series resistor and switch.
// lipo sizing follows the L-shaped carrier PCB in docs/pcb.md: the battery sits
// on the case floor beside the board, and the board's tongue reaches the far
// pogo pin. The divider is removed for lipo because the tongue crosses it.
batt_bay_l = (battery_option == "aaa4") ? 48.0 : 36.0;
elec_bay_l = (battery_option == "aaa4") ? 24.0 : 46.0;
inner_w    = (battery_option == "aaa4") ? 48.0 : 46.0;
divider    = (battery_option == "aaa4");
divider_t  = 1.2;

// Hard ceiling: the camera bottom is 95 mm wide, so outer_l must stay under it.
camera_max_w = 95.0;
divider_h  = 9.0;         // lower than inner_h so leads pass over it

/* [Lid screws] */
// Brass heat-set inserts in the base, machine screws through the lid.
// Defaults are for M2.5 short inserts (3.5 mm OD x 4.0 mm long) — the usual
// small-insert size. Measure YOUR inserts: OD and length vary by supplier.
insert_d      = 3.4;      // bore: insert OD minus ~0.1 for the melt interference
insert_l      = 4.0;      // insert length
insert_relief = 0.5;      // extra bore depth below the insert
insert_lead   = 0.5;      // chamfer at the boss mouth, to start the insert square
// Boss OD needs ~1.5 mm of PETG around the bore or the insert splits it out.
boss_d        = insert_d + 3.0;
lid_screw_d   = 2.7;      // M2.5 clearance
lid_csk_d     = 5.0;      // M2.5 countersunk head
lip_h         = 1.2;
lip_w         = 1.0;

/* [Magnets] */
// Discs bonded into pockets on the outer (camera-facing) face, mating to a
// steel shim on the camera. Bonded, not press-fit: the pocket is deliberately
// loose to leave room for epoxy.
magnets       = true;
magnet_d      = 6.0;
magnet_t      = 2.0;
magnet_fit    = 0.15;     // per-side clearance for adhesive
magnet_recess = 0.3;      // sits below the face so it can't scratch the camera
magnet_back   = 0.8;      // minimum PETG left behind the magnet
magnet_wall   = 2.0;      // PETG around the pocket
// Leave empty for four auto-placed pockets; otherwise list [x, y] outer coords.
magnet_pos    = [];

/* [Pogo pins] */
// Camera interface: spring-loaded pins through the camera-facing face, pressing
// into the base-plate contacts through 3 mm holes in the skin.
//
// Specified pin: Mill-Max 7982-1-15-20-75-14-11-0 (through-hole) — 2.1 mm body,
// 0.7 mm stroke, 60 g mid-stroke, 8 A, gold throughout. Held by the CARRIER PCB.
//
// !! pogo_spacing IS A PLACEHOLDER (50 mm). Measure it on your own base plate.
//
// With only 0.7 mm of stroke, PROTRUSION IS A MEASURED DIMENSION. Tune it with
// pcb_standoff. The echo at the bottom reports the result and warns if it drops
// below the stroke.
//
// The 50 mm span is wider than either bay, so the pins sit in a lane along one
// edge, placed against the whole shell rather than a bay.
pogo_pins    = true;
// The pins are now held by the CARRIER PCB, not by the plastic. The shell only
// needs a clearance bore for each plunger, so pogo_boss is off by default.
pogo_boss    = false;     // true = old press-into-plastic build
pogo_body_d  = 2.1;       // pin barrel (7982 = 2.1 mm)
pogo_clear   = 0.4;       // extra bore clearance when the PCB holds the pin
pogo_above   = 5.2;       // pin height above its mounting surface, from datasheet
pogo_stroke  = 0.7;       // datasheet stroke
pcb_standoff = 2.6;       // PCB underside above the inner floor — sets protrusion
pogo_spacing = 50.0;      // centre-to-centre — PROVISIONAL, confirm on a camera
pogo_lane    = 8.0;       // pin centreline, in from the inner wall
pogo_lead    = 0.4;       // outer lead-in chamfer
pogo_pad_h   = 2.5;       // extra grip length inside, for the press fit
pogo_wall    = 2.5;       // PETG around the bore
// Explicit, not auto-centred: the PCB layout needs the left end of the lane
// clear for J3 and a mounting hole, which pushed both pins 3 mm right.
pogo_pos     = [[21, 10], [71, 10]];   // outer coords; [] = auto-centre

/* [Cutouts] */
// USB-C receptacle on the electronics end wall
usb_w      = 9.6;
usb_h      = 3.8;
usb_y      = 9.0;         // centre, measured from inner wall (y=0 side)
usb_z      = 3.4;         // centre above floor: foam tape + PCB + half receptacle
// Output cable exit — not needed since J1 was dropped. The only things crossing
// the shell wall are the USB-C port, the switch actuator and the pogo plungers.
// Set cable_exit = true to restore it for a wired bench output.
cable_exit = false;
cable_d    = 3.6;
cable_y    = 28.0;
cable_z    = 5.0;
// Slide switch (SS12D00-style) actuator slot on the y=0 long wall
sw_slot_l  = 7.5;
sw_slot_h  = 3.4;
sw_x       = 20.0;        // centre, from the start of the electronics area
sw_z       = 6.0;
// Charge LED window in lid (over the IP2326 LEDs)
led_d      = 2.5;
led_x      = 30.0;        // from the start of the electronics area
led_y      = 8.0;         // from inner y=0 wall

/* [Mounting face] */
// The folding SX-70 has no tripod socket. Default is a flat face for VHB.
// If you screw it to the camera base, list hole centres in outer
// coordinates [x, y] after measuring your body.
mount_holes    = [];      // e.g. [[10,19],[77,19]]
mount_hole_d   = 2.2;
mount_cbore_d  = 4.2;     // head recess from inside
mount_cbore_h  = 0.8;

// ---------- derived ----------
inner_l = batt_bay_l + (divider ? divider_t : 0) + elec_bay_l;
outer_l = inner_l + 2*wall;
outer_w = inner_w + 2*wall;
div_x   = wall + batt_bay_l;              // divider start (outer coords)
elec_x0 = div_x + (divider ? divider_t : 0);   // electronics bay start

mag_pocket_d = magnet_d + 2*magnet_fit;
mag_pocket_h = magnet_t + magnet_recess;
// Pocket is deeper than the floor, so raise a local pad inside to back it.
mag_pad_h    = max(0, mag_pocket_h + magnet_back - floor_t);
mag_pad_d    = mag_pocket_d + 2*magnet_wall;
mag_inset    = mag_pad_d/2 + 1.0;

pogo_pad_d  = pogo_body_d + 2*pogo_wall;
pogo_bore_d = pogo_boss ? pogo_body_d : pogo_body_d + 2*pogo_clear;
// Boss build: bore depth sets protrusion. PCB build: standoff sets it.
pogo_grip  = pogo_boss ? floor_t + pogo_pad_h : floor_t + pcb_standoff;
pogo_stick = pogo_above - pogo_grip;
// 50 mm spacing exceeds either bay, so the pins are placed against the WHOLE
// shell and sit in a clear lane along one edge — see docs/pcb.md.
pogo_cx    = outer_l/2;
pogo_pts = len(pogo_pos) == 0
  ? [ [pogo_cx - pogo_spacing/2, wall + pogo_lane],
      [pogo_cx + pogo_spacing/2, wall + pogo_lane] ]
  : pogo_pos;

// Cavity is deepened by the tallest internal pad so `inner_h` stays clear.
pad_max = max(magnets ? mag_pad_h : 0, (pogo_pins && pogo_boss) ? pogo_pad_h : 0);
cav_h   = inner_h + pad_max;
base_h  = floor_t + cav_h;
mag_pts = len(magnet_pos) == 0
  ? [ [outer_l*0.25, wall + mag_inset], [outer_l*0.75, wall + mag_inset],
      [outer_l*0.25, outer_w - wall - mag_inset],
      [outer_l*0.75, outer_w - wall - mag_inset] ]
  : magnet_pos;

bo = boss_d/2 - 0.6;                       // bosses overlap the walls slightly
boss_pos = [
  [wall + bo,           wall + bo],
  [outer_l - wall - bo, wall + bo],
  [wall + bo,           outer_w - wall - bo],
  [outer_l - wall - bo, outer_w - wall - bo]
];

module rbox(size, r) {
  hull()
    for (x = [r, size[0] - r], y = [r, size[1] - r])
      translate([x, y, 0]) cylinder(r = r, h = size[2]);
}

module slot_y(w, h, depth) {
  // rounded slot, long axis along y, cut through an x-facing wall
  r = h/2;
  hull()
    for (dy = [-(w/2 - r), (w/2 - r)])
      translate([0, dy, 0]) rotate([0, 90, 0]) cylinder(r = r, h = depth, center = true);
}
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

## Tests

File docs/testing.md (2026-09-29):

# Bench testing

Two measurements decide the architecture. Do them before ordering anything expensive.

## 0. Are the base-plate contacts a real power rail?

**Do this first.** The whole pogo-pin approach rests on it, and it is currently an assumption. The community describes these as "test points," which is not the same as the main power rail.

1. Fresh film pack loaded. Meter across the two base-plate contacts — expect ~6 V. **Record which is positive.**
2. Watch the voltage at the contacts while firing the shutter. A real rail sags slightly under ~1 A. A high-impedance test tap **collapses**.
3. Measure contact spacing and hole positions on your own body. Model variation across SX-70 Model 1/2/3, Alpha and SE is likely.

If step 2 collapses, pogo pins onto these contacts will not run the camera and the connection has to move.

## 1. Camera floor voltage

**Question:** how low can the supply go before the camera misbehaves? This sets the regulation target and says whether a fixed 6 V module minus a diode drop is acceptable.

1. Camera on the bench supply via a dummy pack, empty film pack loaded, current limit ~3 A.
2. Start at 6.2 V. Cycle the motor. Note behaviour.
3. Step down in 0.1 V increments, cycling at each step.
4. Record three thresholds: where ejection first sounds sluggish, where the solenoid or electronics misbehave, and where it stalls outright.

Record the numbers here and in the master repair notes — they're useful well beyond this project.

| Voltage | Motor | Solenoid / electronics | Notes |
|---|---|---|---|
| 6.2 V | | | |
| 6.0 V | | | |
| 5.8 V | | | |
| 5.6 V | | | |
| 5.4 V | | | |
| 5.2 V | | | |
| 5.0 V | | | |

## 2. Motor current profile

**Question:** what is the actual peak? Anything above 2 A rules out Option A, because the XTAR cells cap there.

1. 0.1 Ω shunt in the supply's return leg, scope across it (100 mV/A).
2. Capture a full eject-and-recock cycle at 6.0 V.
3. Log: inrush peak and its duration, sustained running current, and stalled-rotor current (jam the mechanism briefly, with the supply current-limited).
4. Repeat with the film door open and closed if behaviour differs.

| Measurement | Value | Notes |
|---|---|---|
| Inrush peak | | Duration: |
| Sustained | | |
| Stalled rotor | | |
| Cycle duration | | |

**Decision rule:** peak below ~1.8 A → build Option A. Above 2 A → build Option B. In between, either works; Option B has margin, Option A has fewer failure modes.

Use the sustained figure and cycle duration to sanity-check the energy-per-cycle estimate in [design.md](design.md), and the stalled figure to choose R1.

## 3. Pack bring-up (before it touches a camera)

Option B:

1. Charger alone on the cells, no load: charge current ≤ 1C, termination at 8.4 V, cell midpoint balanced within ~20 mV. Let the CV taper run to termination before measuring the midpoint — balancing only happens in that final phase, so an early reading tells you nothing. Re-check the midpoint every few months; see [design.md](design.md#balancing) for the drift thresholds.
2. Protection board: confirm it cuts on a deliberate short through a fused lead.
3. Regulator into a resistive dummy load: set output so the camera will see the target voltage under load; confirm the low-voltage cutoff trips near 6.4 V.
4. Switch off: confirm standby current is in the µA range.

Option A:

1. Charge all four cells; confirm they're within ~20 mV of each other off the charger.
2. String voltage 6.0 V under no load, and under a 1 A and 2 A resistive load — watch for fold-back or hiccup.

## 4. In-camera

1. Empty film pack, pack connected, several motor cycles.
2. Scope the rail at the JST during ejection. Look for sag below the floor voltage from test 1, and for any hiccup pattern from regulated cells.
3. Tune R1 from the data: enough impedance to limit a jam, not enough to drag the rail under the floor.
4. Only then load film. Shoot a known scene and compare exposure against a PolaPulse-powered frame, especially if magnets are used for mounting.

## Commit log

2026-09-29 Initial commit: SX-70 external power pack, design v0.4
    Rechargeable camera-mounted supply replacing the PolaPulse cell in the
    film pack, for battery-less i-Type film and dead packs.
    Design:
    - Two architectures carried in parallel; the measured motor peak current
    decides between them (Option A 4x regulated AAA, Option B 2S LiPo).
    - Camera interface is two Mill-Max 7982-1 pogo pins onto the base-plate
    contacts. Nothing is soldered to the camera, which removes the risk of
    destroying a 50-year-old body flex.
    - TPS630702 buck-boost replaces a $35 Pololu module: ~$0.90, no output
    sag across the pack range, 19% smaller pack, and its precise EN
    threshold gives back the soft low-voltage cu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
    [bom-option-a-aaa.csv, bom-option-b-lipo.csv, digikey-order.csv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]
2026-10-02 Move order records out of the tracked tree
    Order numbers, exact prices, dates and vendor correspondence came from
    personal email and tie the project to an individual PCBWay account. None
    of it helps a reader reproduce the work.
    - Add private/ (gitignored) holding the PCBWay order records, with a
    README stating what belongs there and the test for moving anything out.
    - README and docs/flex-order.md keep what is actually useful: that both
    parts were ordered, the ~$135 ballpark for 10 assembled boards, the
    18-20 day build and the Golden Week overlap.
    - Drop the per-line cost breakdown, product IDs, filenames, exact dates
    and the vendor rep's contact details.
    The as-built fab parameter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
2026-10-02 Sync docs with TPS630702 regulator; add CLAUDE.md and venv setup (#1)
    * Sync docs with the TPS630702 regulator and current PCB placement
    The BOM, netlist and PCB scripts had moved to the TPS630702 buck-boost
    and a 2 x 220 uF C1, but the prose docs still described the Pololu
    module and a 1000 uF C1.
    - README and design.md: Option B is a buck-boost; Pololu is U3-alt.
    Block diagrams and BOM table now show the TPS630702, C1a/C1b and F1.
    Changelog gets an Unreleased entry for the regulator swap.
    - pcb.md: status reflects the generated KiCad file; placement table
    recomputed from the scripts (board-local + 3 mm); "verified clear"
    claims now say they check bodies only, not courtyards; F1 a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
